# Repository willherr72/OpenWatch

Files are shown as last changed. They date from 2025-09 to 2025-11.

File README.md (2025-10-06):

# OpenWatch - Open Source Smartwatch

An open-source smartwatch project developed as a school final project. This repository contains all the necessary files for building a complete smartwatch, including mechanical designs, PCB layouts, and firmware/software code.

## 📁 Project Structure

```
OpenWatch/
├── Code/                    # All code files
│   ├── Firmware/           # Embedded firmware code
│   └── Software/           # Application software code
├── KiCad/                  # PCB design files and schematics
│   ├── Smartwatch.kicad_pcb    # Main PCB layout
│   ├── Smartwatch.kicad_sch    # Main schematic
│   ├── Smartwatch.kicad_pro    # Project file
│   ├── Usermade.pretty/        # Custom component footprints
│   └── Smartwatch-backups/     # Backup files
└── Mechanical/             # 3D models and mechanical designs
    ├── Watch Assm.SLDASM       # Main assembly
    ├── Watch Body.SLDPRT       # Watch body
    ├── Watch Top.SLDPRT        # Watch top
    └── Watch PCB.SLDPRT        # PCB mechanical model
```

## 🚀 Getting Started

### Prerequisites

- **Git** - Version control system
- **KiCad** - For PCB design and schematic editing
- **SolidWorks** (or compatible CAD software) - For mechanical design files
- **Arduino IDE** - For firmware development
- **Code editor** (VSCode, Cursor, etc.) - For software development

### Installation

1. Clone this repository to your local machine
2. Install the required software listed above
3. Open the appropriate files in their respective applications

## 📚 Git Workflow Guide

**⚠️ IMPORTANT: NEVER EDIT DIRECTLY IN MASTER BRANCH! ⚠️**

All team members MUST create a branch for their work, make changes in that branch, and then merge to main. This keeps the project organized and prevents conflicts.

This section provides the essential Git commands you'll use daily. Keep it simple and follow these steps exactly.

### First Time Setup (Do this once)

#### 1. Clone the Repository
```bash
# Clone the repository to your local machine
git clone https://github.com/willherr72/OpenWatch.git

# Navigate to the project directory
cd OpenWatch
```

#### 2. Configure Git (First time only)
```bash
# Set your name and email
git config --global user.name "Your Name"
git config --global user.email "your.email@example.com"
```

## 🚀 Daily Workflow (Follow These Steps Every Time)

### Step 1: Start Your Work Session
```bash
# 1. Get the latest changes from the team
git pull origin master

# 2. Create a new branch for your work (replace 'your-feature' with what you're working on)
git checkout -b feature/your-feature

# Example: git checkout -b feature/touch-screen
# Example: git checkout -b fix/power-bug
# Example: git checkout -b docs/update-readme
```

### Step 2: Make Your Changes
```bash
# 3. Make your changes to files (edit in your code editor)
# 4. Check what files you've changed
git status

# 5. Add your changes
git add .

# 6. Save your work with a message
git commit -m "Add your feature description here"

# 7. Push your branch to GitHub
git push origin feature/your-feature
```

## 📝 Essential Commands Cheat Sheet

| What you want to do | Command |
|---|---|
| See what files changed | `git status` |
| Add all changes | `git add .` |
| Save your work | `git commit -m "Your message"` |
| Upload to GitHub | `git push origin feature/your-branch` |
| Get team's latest work | `git pull origin master` |
| Create new branch | `git checkout -b feature/your-name` |
| Switch to master | `git checkout master` |
| See all branches | `git branch` |

## ⚠️ Important Rules

1. **ALWAYS create a branch before making changes**
2. **NEVER work directly in master branch**
3. **Use descriptive branch names** (feature/touch-screen, fix/power-bug, etc.)
4. **Write clear commit messages** (what you did, not how you did it)
5. **Pull before you push** (get latest changes first)

## 🔧 Development Guidelines

### Code Organization
- **Firmware**: Place all embedded code in `Code/Firmware/`
- **Software**: Place application code in `Code/Software/`
- **Mechanical**: Keep all CAD files in `Mechanical/`
- **PCB**: All KiCad files go in `KiCad/`

### Branch Naming Examples
- `feature/touch-screen-support`
- `fix/power-management-bug`
- `docs/update-readme`
- `feature/watch-face-display`

## 🤝 Contributing

1. Create a feature branch (`git checkout -b feature/amazing-feature`)
2. Make your changes
3. Commit your changes (`git commit -m 'Add some amazing feature'`)
4. Push to the branch (`git push origin feature/amazing-feature`)
5. Merge to master following the workflow above

## 📋 Project Status

This project is currently in active development as a school final project. The repository contains:

- ✅ Basic project structure
- ✅ KiCad PCB design files
- ✅ SolidWorks mechanical models
- 🔄 Firmware development 
- 🔄 Software development 

## 📄 License

This project is open source. Please check the LICENSE file for details.

---

**Happy Coding! 🚀**

Remember: When in doubt, `git status` is your friend!

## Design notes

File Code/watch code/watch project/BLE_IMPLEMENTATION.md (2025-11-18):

# BLE Implementation Guide for OpenWatch

## Overview

OpenWatch supports **two connection modes**: WiFi (full features) and BLE (battery saver). You can switch between them in Settings.

### Why Not Run Both Simultaneously?

While ESP32-S3 technically supports WiFi/BLE coexistence, it uses [time-division multiplexing](https://docs.espressif.com/projects/esp-idf/en/latest/esp32/api-guides/coexist.html) which can cause:
- Performance issues and packet delays
- Complex timing bugs
- Unpredictable behavior

**Solution**: Clean separation with mode toggle - just like Apple Watch and Samsung Galaxy Watch do it!

## Connection Modes

### 📡 WiFi Mode (Default) - Full Features
- ✅ Time sync via NTP servers
- ✅ Weather from NOAA API
- ✅ Full internet connectivity
- **Use when**: At home, office, or anywhere with WiFi
- **Power**: ~100-300mA during active use

### 🔵 BLE Mode - Battery Saver  
- ✅ Time sync from paired phone
- 🚧 Future: Notifications (when vibration motor added)
- 🚧 Future: Music control, find-my-phone
- **Use when**: Away from WiFi but near your phone
- **Power**: ~15-30mA during active use (10x more efficient!)
- **Note**: Weather requires WiFi - switch back to WiFi mode for weather updates

## How to Use

### On the Watch

1. Navigate to the **Settings** screen (upward swipe from watch face)
2. You'll see a **Connection** section with a toggle switch:
   - **WiFi** (left) - Default mode, connects to your WiFi network
   - **BLE** (right) - BLE mode, connects to your phone via Bluetooth
3. Toggle the switch to change modes
4. The "Mode" label will update to show the current mode

### On Your Phone

You'll need a companion app or BLE terminal to send data to the watch. Here are the BLE service UUIDs:

#### Time Sync Service (Currently Implemented)
- **Service UUID**: `12340000-1234-1234-1234-123456789abc`
- **Time Sync Characteristic**: `12340001-1234-1234-1234-123456789abc`
  - **Type**: Write
  - **Format**: 4-byte Unix timestamp (little-endian)
  - **Example**: Send `Math.floor(Date.now() / 1000)` from JavaScript

#### Future Services
- **Notification Service**: Coming when vibration motor is added
- **Music Control**: Coming in future update
- **Find My Phone**: Coming in future update

**Note**: Weather service was removed - weather requires internet, so use WiFi mode instead!

## Implementation Details

### File Structure

```
include/
  └── ble_handler.h         # BLE handler header
src/
  └── ble_handler.cpp       # BLE implementation
  └── app_manager.cpp       # Updated with BLE mode toggle
  └── main.cpp              # BLE initialization and updates
  └── wifi_handler.cpp      # Mode-aware WiFi handling
```

### Key Components

#### 1. BLE Handler (`ble_handler.cpp`)
- Manages BLE server, services, and characteristics
- Handles connection/disconnection callbacks
- Processes incoming time and weather data
- Provides mode switching functionality

#### 2. Settings Screen (`app_manager.cpp`)
- New WiFi/BLE toggle switch
- Visual mode indicator
- Event handler for mode switching

#### 3. Main Loop (`main.cpp`)
- BLE initialization
- BLE update calls
- Mode-aware time synchronization
- Mode-aware connectivity indicator

#### 4. Weather App (`app_manager.cpp`)
- Checks connection mode
- Fetches weather from WiFi API or BLE
- Displays appropriate status messages

### Mode Switching Behavior

When switching **FROM WiFi TO BLE**:
1. WiFi is disconnected and disabled
2. BLE services are started
3. Watch begins advertising as "OpenWatch"
4. WiFi icon shows BLE connection status

When switching **FROM BLE TO WiFi**:
5. BLE services are stopped and resources freed
6. WiFi reconnects automatically (handled by existing WiFi handler)
7. WiFi icon shows WiFi connection status

### Data Flow

#### Time Sync
```
Phone App → BLE Time Characteristic → ble_handler.cpp → System Time → Watch Face
```

#### Weather Data
```
Phone App → BLE Weather Characteristics → ble_handler.cpp → weather_data → Weather Screen → Watch Face
```

## No Companion App Needed!

You can sync time from your phone using existing BLE tools:

### Option 1: Use BLE Scanner Apps (Easiest)
**Android**: 
- Download "nRF Connect" from Play Store
- Connect to "OpenWatch"
- Find Time Sync characteristic (`12340001-...`)
- Write 4-byte timestamp

**iOS**:
- Download "LightBlue" from App Store  
- Connect to "OpenWatch"
- Find Time Sync characteristic
- Write timestamp as hex value

### Option 2: Web Bluetooth (Any Phone Browser)
Open this code in Chrome/Edge on your phone:

```html
<!DOCTYPE html>
<html>
<body>
<button onclick="syncTime()">Sync Time to OpenWatch</button>
<script>
let device, timeChar;

async function syncTime() {
  if (!timeChar) {
    // Connect first time
    device = await navigator.bluetooth.requestDevice({
      filters: [{ name: 'OpenWatch' }],
      optionalServices: ['12340000-1234-1234-1234-123456789abc']
    });
    const server = await device.gatt.connect();
    const service = await server.getPrimaryService('12340000-1234-1234-1234-123456789abc');
    timeChar = await service.getCharacteristic('12340001-1234-1234-1234-123456789abc');
  }
  
  // Send current time
  const timestamp = Math.floor(Date.now() / 1000);
  const buffer = new ArrayBuffer(4);
  new DataView(buffer).setUint32(0, timestamp, true);
  await timeChar.writeValue(buffer);
  alert('Time synced!');
}
</script>
</body>
</html>
```

Save this as `openwatch_sync.html` and open in your phone browser!

## Testing

### BLE Mode Testing
1. Upload firmware to watch
2. Navigate to Settings and switch to BLE mode
3. Watch should start advertising as "OpenWatch"
4. Connect from phone using BLE scanner app (e.g., nRF Connect, LightBlue)
5. Send time sync data to verify time updates
6. Send weather data to verify weather screen updates

### WiFi Mode Testing
1. Switch back to WiFi mode in Settings
2. Watch should reconnect to WiFi automatically
3. Verify time sync via NTP
4. Verify weather fetch from NOAA API

## Troubleshooting

### Watch Not Advertising
- Ensure you're in BLE mode (check Settings screen)
- Reboot the watch
- Check serial monitor for "[BLE] Services started and advertising!"

### Phone Can't Connect
- Make sure Bluetooth is enabled on phone
- Try disconnecting and reconnecting
- Check serial monitor for "[BLE] Client connected!" message

### Time Not Syncing
- Verify timestamp format (4-byte little-endian Unix time)
- Check serial monitor for "[BLE] Received time sync" message
- Try sending timestamp again (BLE sometimes drops first packet)

### Weather Not Showing
- Weather requires WiFi mode! Switch to WiFi mode in Settings
- BLE mode is for time sync and future notifications only

## Power Consumption

BLE mode is generally more power-efficient than WiFi for smartwatch applications:
- **WiFi**: ~100-300mA during active connection
- **BLE**: ~15-30mA during active connection
- **BLE Advertising**: ~10-20mA

Consider using BLE mode for better battery life when you're near your phone.

## Security Considerations

The current implementation uses **unencrypted** BLE connections. For production use, consider:
- Adding BLE pairing/bonding
- Implementing encryption for sensitive data
- Adding authentication mechanisms
- Restricting which devices can connect

## Roadmap

### Next (When Vibration Motor Added)
- [ ] Notification service - get phone notifications on watch
- [ ] Call alerts - vibrate for incoming calls
- [ ] Text message previews

### Future
- [ ] Music control - play/pause/skip from watch
- [ ] Find-my-phone - make phone ring from watch
- [ ] Battery level reporting to phone
- [ ] Secure pairing with encryption

### Won't Implement
- ~~Weather via BLE~~ - Weather needs internet, use WiFi mode
- ~~Dual WiFi+BLE~~ - Time-division multiplexing adds complexity/bugs

---

**Note**: This is a development implementation. For production use, additional security and error handling should be implemented.

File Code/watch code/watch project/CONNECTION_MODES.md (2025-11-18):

# OpenWatch Connection Modes - Quick Reference

## TL;DR
- **WiFi Mode** (default): Time + Weather ✅
- **BLE Mode** (battery saver): Time only, notifications later 🚧

## When to Use Each Mode

### Use WiFi Mode When:
- 🏠 At home or office with WiFi
- 🌤️ You want weather updates
- 🌐 You need full internet features
- 🔌 Near a charger (uses more power)

### Use BLE Mode When:
- 🚶 Away from WiFi but near your phone
- 🔋 Want to save battery (10x more efficient!)
- ⏰ Only need time sync
- 📱 Waiting for notification features (coming soon)

## How to Switch Modes

1. Swipe **UP** from watch face → Settings
2. Toggle switch: **WiFi** ← → **BLE**
3. Current mode shown below switch

## What Works in Each Mode

| Feature | WiFi Mode | BLE Mode |
|---|---|---|
| Time Sync | ✅ NTP (auto) | ✅ From phone (manual) |
| Weather | ✅ NOAA API | ❌ Need WiFi |
| Battery Life | ~8-12 hours | ~80-120 hours |
| Notifications | ❌ | 🚧 Coming soon |

## Time Sync in BLE Mode

Since you don't have WiFi in BLE mode, sync time from your phone:

### Quick Method (No App Needed!)
1. Open Chrome on your phone
2. Go to: `https://googlechromelabs.github.io/web-bluetooth/demos/`
3. Find "Generic Access" demo
4. Connect to "OpenWatch"
5. Write timestamp to characteristic `12340001-1234-1234-1234-123456789abc`

### Using BLE Scanner App
1. Download "nRF Connect" (Android) or "LightBlue" (iOS)
2. Connect to "OpenWatch"
3. Find Time Service → Time Sync characteristic
4. Write current Unix timestamp (4 bytes, little-endian)

**Tip**: Your phone likely has apps that can do this automatically!

## Technical Details

### Why Not Both at Once?
ESP32-S3 CAN run WiFi+BLE simultaneously, but it uses time-division multiplexing which causes:
- Packet delays and dropped connections
- Timing bugs and race conditions  
- Unpredictable performance

Clean separation = reliable operation! (Same approach as Apple Watch, Samsung Galaxy Watch)

### Power Consumption
- **WiFi active**: 100-300mA
- **BLE active**: 15-30mA
- **Deep sleep**: <1mA (future)

Switching to BLE mode when away from WiFi can **extend battery life by 10x**!

## Future Features (BLE Mode)

When vibration motor is added:
- 📱 Phone call alerts
- 💬 Text message notifications
- 📧 Email previews
- 🎵 Music control
- 📍 Find my phone

## Common Issues

**Q: Weather shows "Weather needs WiFi" in BLE mode**  
A: Correct! Weather requires internet. Switch to WiFi mode for weather.

**Q: Time not syncing in BLE mode**  
A: You need to manually sync from phone. See "Time Sync in BLE Mode" above.

**Q: Can I leave it in WiFi mode all the time?**  
A: Yes! WiFi is the default and works great when you have WiFi available.

**Q: Does BLE mode use my phone's data?**  
A: No! BLE is direct watch↔phone connection. No cellular data used.

## Recommendation

**Start with WiFi mode** (default) - it just works!  
Switch to **BLE mode** when you're away from WiFi to save battery.

---

*For detailed technical documentation, see `BLE_IMPLEMENTATION.md`*

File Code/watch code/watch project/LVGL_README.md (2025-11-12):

# OpenWatch - LVGL Edition

## Overview

This smartwatch firmware has been migrated to use **LVGL (Light and Versatile Graphics Library)** for a modern, beautiful UI with smooth animations and better graphics rendering.

## Features

### Current Implementation

- ✅ **Beautiful Modern Watch Face**
  - Large, clear time display (12-hour format)
  - Circular seconds indicator arc
  - Day of week and date display
  - WiFi status indicator
  - Smooth animations
  - Dark theme with cyan accents
  - Subtle glow effects

- ✅ **LVGL Integration**
  - LVGL v9.2.2
  - Optimized for 240x240 round GC9A01A display
  - Double-buffered rendering for smooth updates
  - TFT_eSPI hardware acceleration

- ✅ **Touch Input**
  - CST816S touch controller support
  - Integrated with LVGL input system

- ✅ **Power Management**
  - Button-triggered sleep mode
  - Low power light sleep
  - Wake on button press

- ✅ **Time Sync**
  - WiFi-based NTP time synchronization
  - Automatic timezone handling (CDT/CST)
  - Visual sync status indicators

## Hardware

- **MCU**: ESP32-S3 (Adafruit QT Py ESP32-S3)
- **Display**: GC9A01A 240x240 round TFT (SPI)
- **Touch**: CST816S capacitive touch controller (I2C)
- **Buttons**: 2x physical buttons

## Pin Configuration

```
Display (SPI):
- SCLK: GPIO 12
- MOSI: GPIO 11
- MISO: GPIO 13
- CS:   GPIO 10
- DC:   GPIO 39
- RST:  GPIO 40
- BL:   GPIO 7

Touch (I2C):
- SDA:  GPIO 8
- SCL:  GPIO 9
- INT:  GPIO 41
- ADDR: 0x15

Buttons:
- Primary: GPIO 18
- Menu:    GPIO 14

Power:
- Rail: GPIO 17 (set HIGH)
```

## Building

1. Open project in PlatformIO
2. Build: `pio run`
3. Upload: `pio run -t upload`
4. Monitor: `pio device monitor`

## Usage

### Buttons

- **Primary Button**
  - Long Press: Enter sleep mode

- **Menu Button**
  - Short Press: Toggle WiFi (for time sync)

### Watch Face

The watch face displays:
- Current time (12-hour format)
- Day of week (top)
- Date (bottom)
- Circular seconds indicator
- WiFi status icon (green when connected)
- Dimmed display when time not synced

## Configuration

### WiFi Credentials

Edit `include/secrets.h`:
```cpp
#define WIFI_SSID "your-ssid"
#define WIFI_PASSWORD "your-password"
```

### LVGL Settings

Configuration in `lv_conf.h`:
- Memory: 64KB heap
- Color depth: 16-bit (RGB565)
- Buffer: 40 lines (9600 pixels per buffer)
- Theme: Dark mode enabled
- Fonts: Montserrat 12-48pt

## Architecture

```
┌─────────────────────────────────────┐
│           main.cpp                  │
│  (Main loop, WiFi, time sync)       │
└─────────────────┬───────────────────┘
                  │
        ┌─────────┴─────────┐
        │                   │
┌───────▼────────┐  ┌───────▼────────┐
│  LVGL Display  │  │  LVGL Touch    │
│   (TFT_eSPI)   │  │  (CST816S)     │
└───────┬────────┘  └───────┬────────┘
        │                   │
        └─────────┬─────────┘
                  │
        ┌─────────▼─────────┐
        │   Watch Face UI   │
        │  (LVGL widgets)   │
        └───────────────────┘
```

## Future Enhancements

- Add more watch faces (analog, digital variants)
- App menu system
- Timer/stopwatch app
- Fitness tracking
- Weather display
- Notification system
- Settings menu
- Battery level indicator

## Libraries Used

- **LVGL** (v9.2.2) - Graphics library
- **TFT_eSPI** (v2.5.43) - Display driver
- **ArduinoJson** (v7.4.2) - JSON parsing
- **CST816S** (custom) - Touch driver

## Notes

- LVGL tasks run at ~30 FPS
- Watch face updates every 1 second
- WiFi disabled by default (power saving)
- Time persists via ESP32 RTC when WiFi off
- Timezone: Central Time (UTC-5)

## Troubleshooting

### Display not working
- Check SPI pin definitions in platformio.ini
- Verify TFT_BL (backlight) is HIGH
- Ensure LVGL buffer size fits in memory

### Touch not responding
- Check I2C pins and address (0x15)
- Verify pull-up resistors on I2C lines
- Check INT pin connection

### Time not syncing
- Press Menu button to enable WiFi
- Check WiFi credentials in secrets.h
- Monitor serial output for NTP status

## License

[Your License Here]

## Author

OpenWatch Project

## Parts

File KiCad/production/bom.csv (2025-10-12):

Designator | Footprint | Quantity | Value | LCSC Part #
AE1 | 1206 | 1 | Antenna_Shield
AE2 | 1206 | 1 | W3011
BT1 | PinHeader_1x02_P1.27mm_Vertical | 1 | 1S1P LiPo
C1, C6 | 0402 | 2 | 1u
C10, C2, C22, C35, C8 | 0603 | 5 | 10u
C11, C12, C13, C14, C19, C20, C21, C23, C24, C25, C26, C3, C37, C38, C4, C5, C9 | 0402 | 17 | 100n
C15, C16 | 0402 | 2 | 10p
C17, C18, C31, C32 | 0402 | 4 | 22p
C27, C28, C33, C34 | 0402 | 4 | DNP
C7 | 0402 | 1 | 10u
D1, D2, D3 | D_SOD-323 | 3 | D_Small
J1 | PinHeader_1x04_P2.54mm_Vertical | 1 | 5358
JP1 | SolderJumper-2_P1.3mm_Open_RoundedPad1.0x1.5mm | 1 | BOOT SEL
L1, L2, R24, R25, R4 | 0402 | 5 | 0
M1 | PinHeader_1x02_P1.27mm_Vertical | 1 | LCM1027B3605F
Q1 | TSOT-23 | 1 | AO3400A
R1 | 0402 | 1 | 10
R10, R14, R15, R16, R19, R2, R20, R21, R22, R23, R26, R29, R3, R6 | 0402 | 14 | 10k
R11, R7 | 0402 | 2 | 1M
R12 | 0402 | 1 | 250K
R13 | 0402 | 1 | 2K
R17, R18 | 0402 | 2 | 4.7k
R27, R28 | 0402 | 2 | 22
R5, R8, R9 | 0402 | 3 | 1k
SW1 | JXTCONN TS-1010-S26 | 1 | SW_Push
SW2 | JXTCONN TS-1010-S26 | 1 | JXTCONN TS-1010-S26
U1 | LGA-28_5.2x3.8mm_P0.5mm | 1 | BNO055
U10 | quectel lc76g | 1 | Quectel LC76G
U11 | SOT-23-5 | 1 | MIC5504-1.8YM5
U12 | QFN-56-1EP_7x7mm_P0.4mm_EP4x4mm | 1 | ESP32-S3
U13 | Bosch_LGA-8_2x2.5mm_P0.65mm_ClockwisePinNumbering | 1 | BMP280
U14 | DFN-6-1EP_3x3mm_P0.95mm_EP1.7x2.6mm | 1 | LD39100PU33R
U2 | SOT-23-5 | 1 | MIC5504-3.3YM5
U3 | Maxim_OLGA-14_3.3x5.6mm_P0.8mm | 1 | MAX30102
U4 | DFN-8-1EP_3x2mm_P0.5mm_EP1.7x1.4mm | 1 | MCP9808_DFN
U5 | SOT-583-8 | 1 | TPS2116DRL
U6 | SOT-23-6 | 1 | USBLC6-2SC6
U7 | SOT-23-5 | 1 | BRCL4054DME
U9 | JST_ZE_B13B-ZESK-D_1x13_P1.50mm_Vertical | 1 | GC9A01_IPS_Display_w/_Touch
Y1 | Crystal_SMD_2016-4Pin_2.0x1.6mm | 1 | 40MHz
Y2, Y3 | EPSON Q13FC13500004 | 2 | 32.768KHz

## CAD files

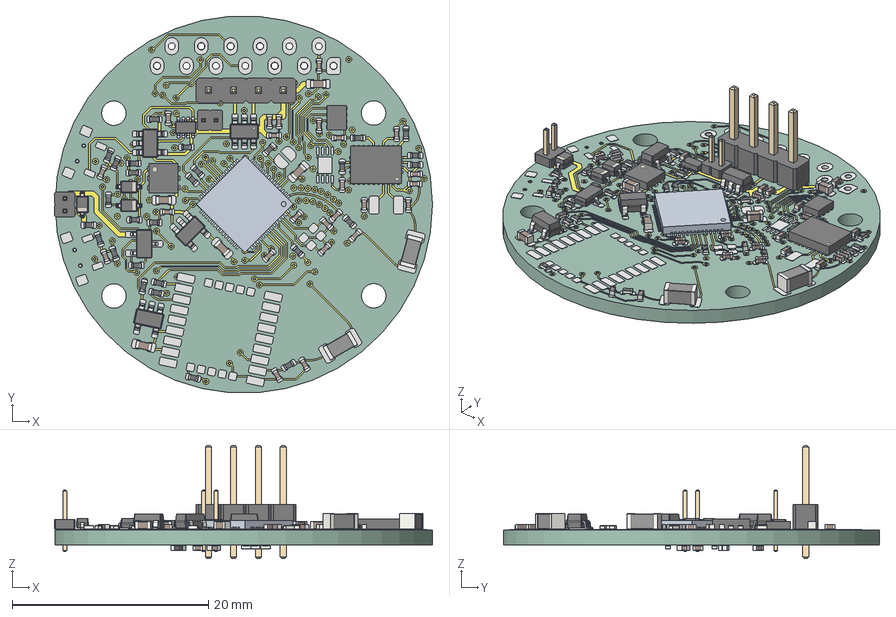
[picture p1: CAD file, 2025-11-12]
KiCad/Smartwatch.step
38.6 x 38.4 x 11.5 mm
C_0402_1005Metric x 30
R_0402_1005Metric x 31
PinHeader_1x02_P1.27mm_Vertical x 2
C_0603_1608Metric x 5
L_1206_3216Metric x 2
SOT-23-5 x 3
TSOT-23
D_SOD-323 x 3
SOT-23-6
LGA-28_5.2x3.8mm_P0.5mm
SOT-583-8
Bosch_LGA-8_2x2.5mm_P0.65mm_ClockwisePinNumbering
DFN-6-1EP_3x3mm_P0.95mm_EP1.7x2.6mm
PinHeader_1x04_P2.54mm_Vertical
Smartwatch 1.71.1
Smartwatch_copper
Smartwatch_pad
Smartwatch_via
Smartwatch_PCB

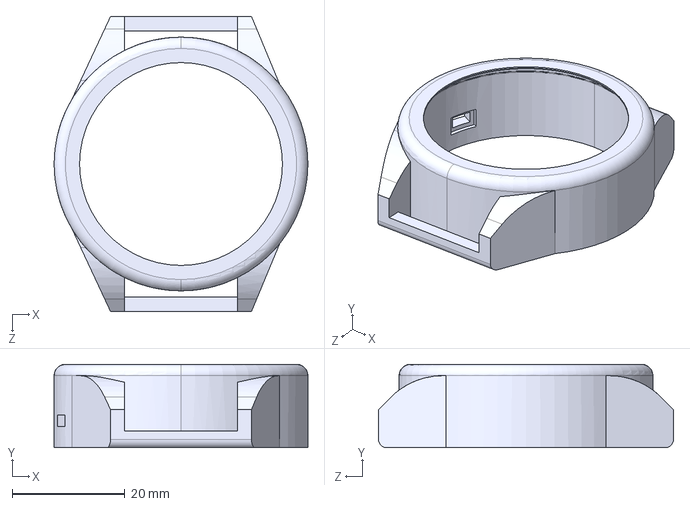
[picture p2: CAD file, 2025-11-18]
Mechanical/.step/Watch Body - Velcro.STEP
45.0 x 14.8 x 52.3 mm

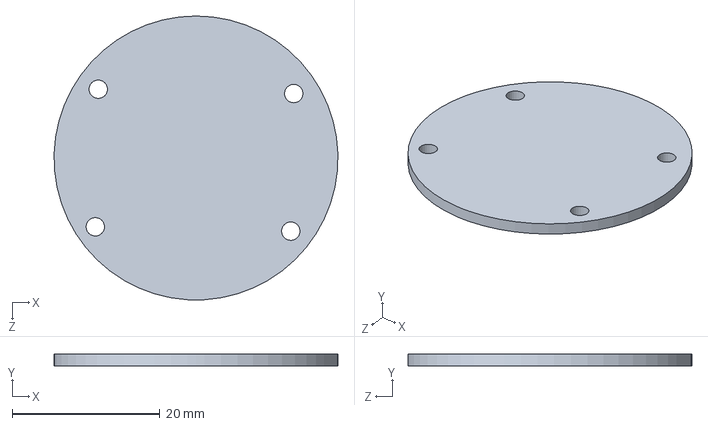
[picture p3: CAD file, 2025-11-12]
Mechanical/Watch PCB.SLDPRT
38.5 x 1.60 x 38.5 mm

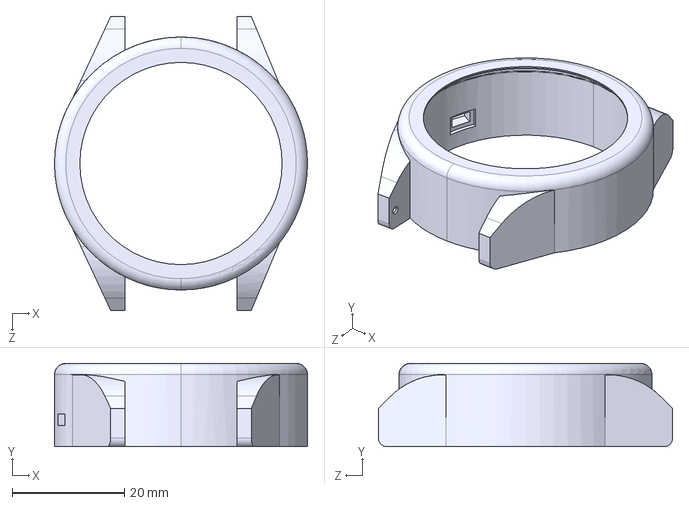
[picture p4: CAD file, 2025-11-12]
Mechanical/.step/Watch Body.STEP
45.0 x 14.8 x 52.3 mm

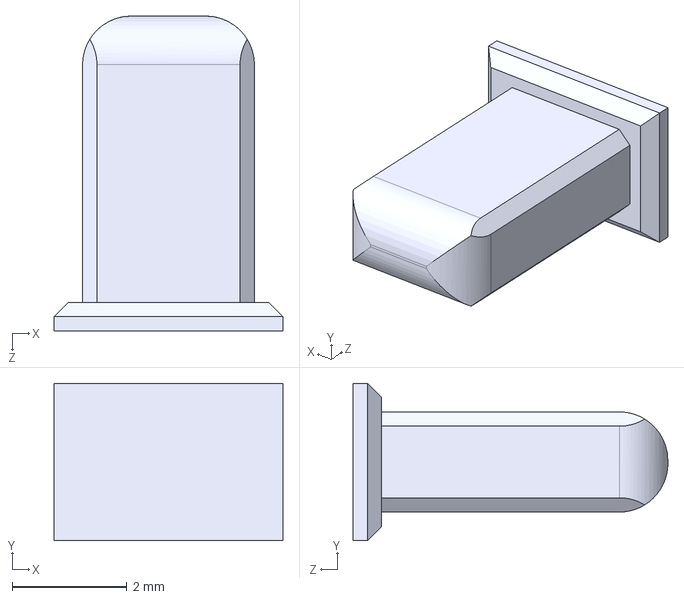
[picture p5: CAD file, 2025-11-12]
Mechanical/.step/Watch Buttons.STEP
4.00 x 2.75 x 5.50 mm

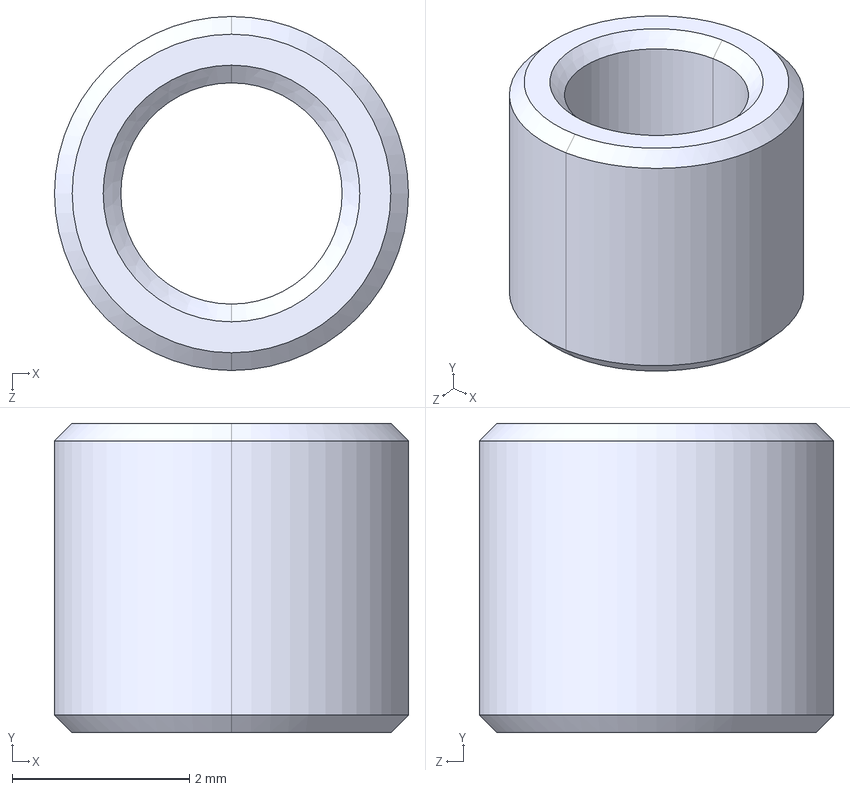
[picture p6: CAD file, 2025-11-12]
Mechanical/.step/Watch Spacer.STEP
4.00 x 3.50 x 4.00 mm

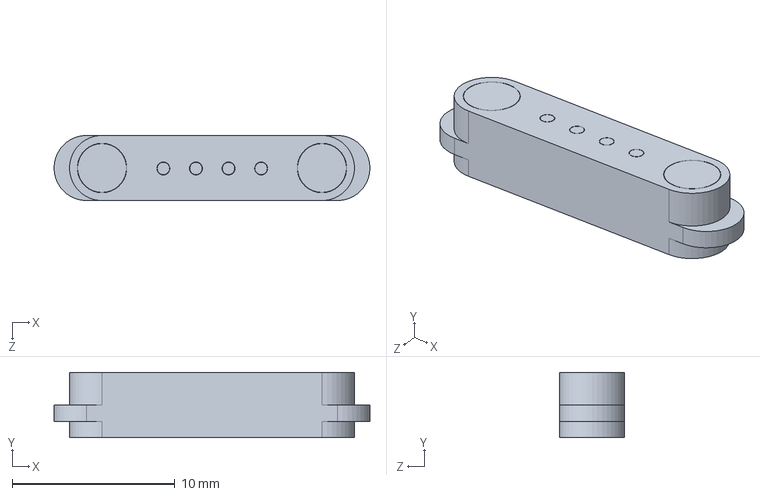
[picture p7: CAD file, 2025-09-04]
Mechanical/Magnetic Pogo Connector 4 Pin.SLDPRT
19.4 x 4.00 x 4.00 mm

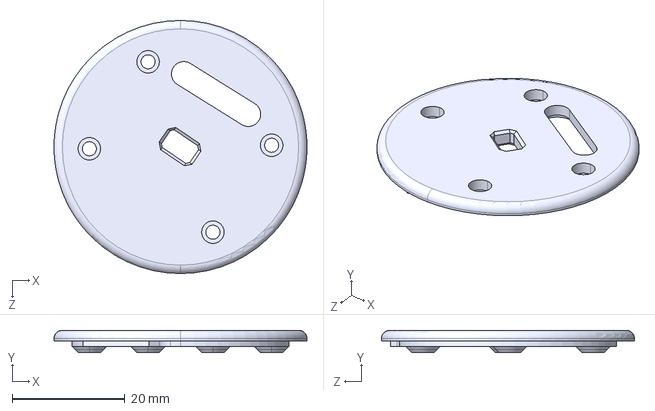
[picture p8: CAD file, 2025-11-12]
Mechanical/.step/Watch Top.STEP
45.0 x 4.00 x 45.0 mm

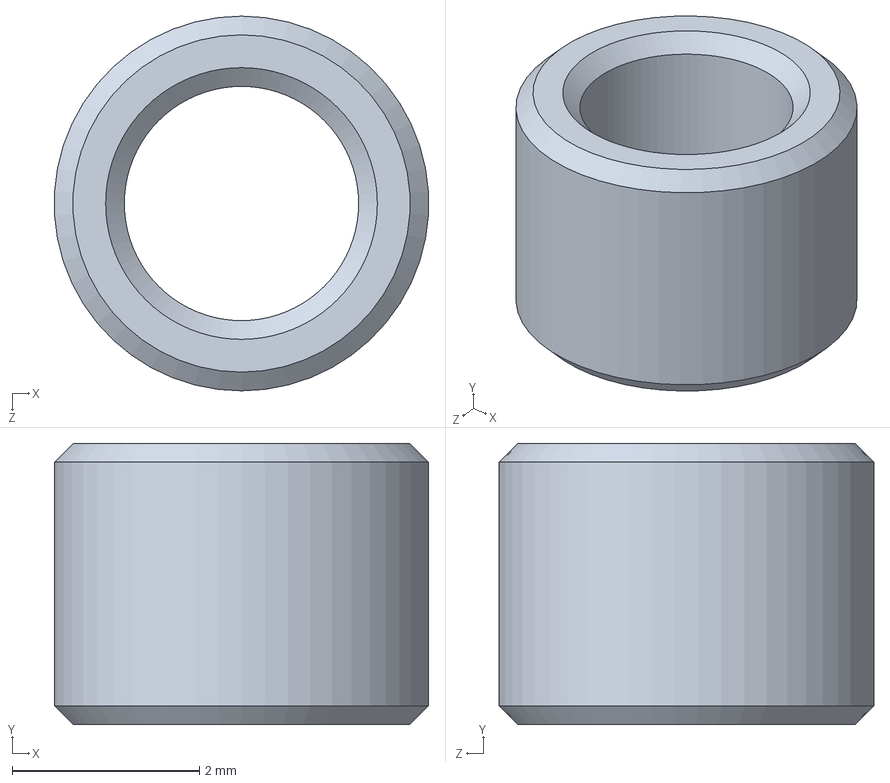
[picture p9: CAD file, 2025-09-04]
Mechanical/Watch Spacer - Long.SLDPRT
3.99 x 3.00 x 4.00 mm

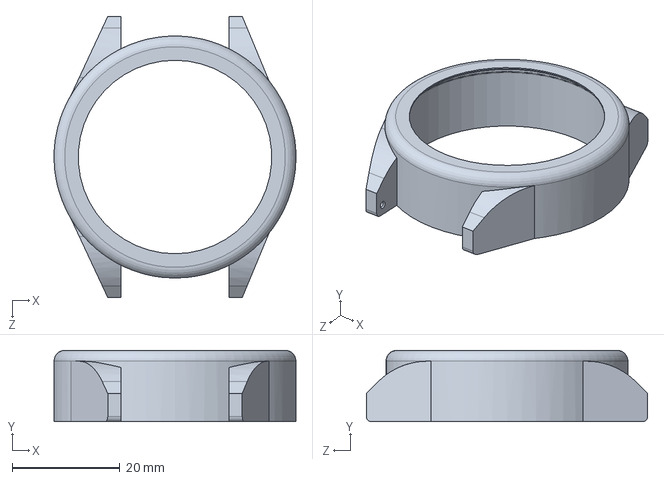
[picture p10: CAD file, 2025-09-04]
Mechanical/.step/Watch Body - First.SLDPRT
45.0 x 13.3 x 52.3 mm

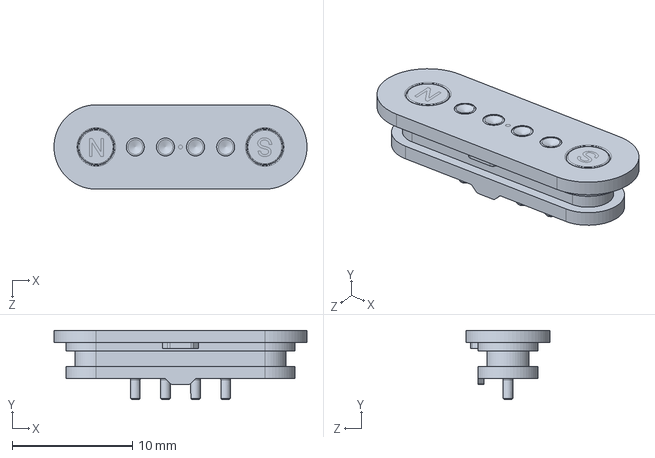
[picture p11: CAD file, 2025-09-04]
Mechanical/Magnetic Pogo Connector 4 Pin (Type 1).SLDPRT
21.0 x 5.75 x 7.00 mm

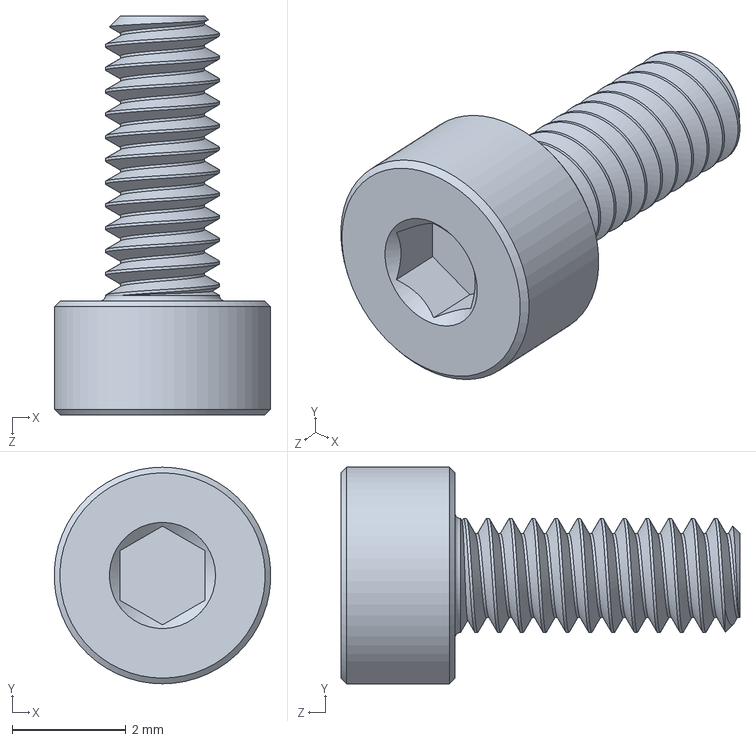
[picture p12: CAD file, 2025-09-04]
Mechanical/91290A012_Alloy Steel Socket Head Screw.SLDPRT
3.79 x 3.80 x 7.00 mm

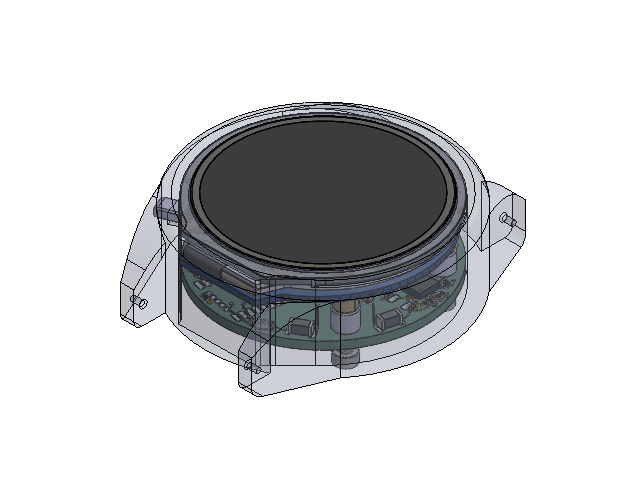
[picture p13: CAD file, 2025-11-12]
Mechanical/Watch Assm.SLDASM
Watch Body
1_28INCH-240X240-TFT_1.stp
1_28INCH-240X240-TFT-TOUCH_1.stp
1_28INCH_TOUCH_LCD-PCBA_1.stp
STUDS-M2XH2_5_1.stp x 4
Watch Spacer x 4
91290A015_Alloy Steel Socket Head Screw x 4
Magnetic Pogo Connector 4 Pin
Smartwatch 1.71.1.step
C_0402_1005Metric.step x 30
R_0402_1005Metric.step x 31
PinHeader_1x02_P1.27mm_Vertical.step x 2
C_0603_1608Metric.step x 5
L_1206_3216Metric.step x 2
SOT-23-5.step x 3
TSOT-23.step
D_SOD-323.step x 3
SOT-23-6.step
LGA-28_5.2x3.8mm_P0.5mm.step
SOT-583-8.step
Bosch_LGA-8_2x2.5mm_P0.65mm_ClockwisePinNumbering.step
DFN-6-1EP_3x3mm_P0.95mm_EP1.7x2.6mm.step
PinHeader_1x04_P2.54mm_Vertical.step
Smartwatch_copper.step
Smartwatch_pad.step
Smartwatch_via.step
Smartwatch_PCB.step
Watch Buttons x 2

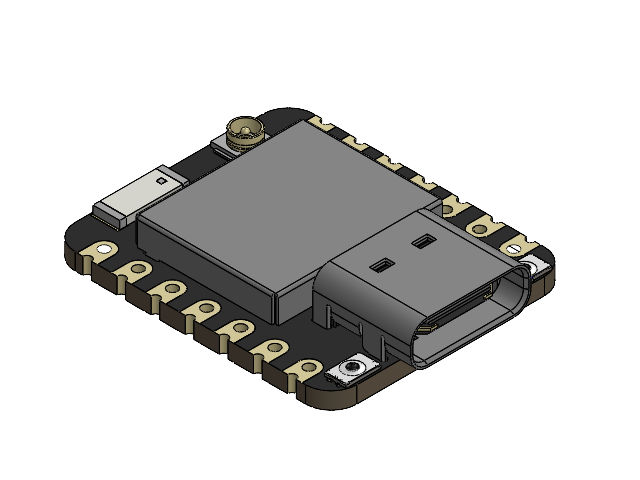
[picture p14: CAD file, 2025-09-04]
Mechanical/.step/Seeed Studio XIAO ESP32-C6.SLDASM
BOSS-EXTRUDE14_8_.step
BOSS-EXTRUDE7_4_.step
BOSS-EXTRUDE7_3_.step
BOSS-EXTRUDE14_4_.step
BOSS-EXTRUDE14_2_.step
BOSS-EXTRUDE14_11_.step
BOSS-EXTRUDE7_7_.step
BOSS-EXTRUDE14_9_.step
BOSS-EXTRUDE14_3_.step
BOSS-EXTRUDE14_7_.step
MIRROR2.step
BOSS-EXTRUDE14_5_.step
BOSS-EXTRUDE14_12_.step
BOSS-EXTRUDE7_8_.step
BOSS-EXTRUDE7_1_.step
BOSS-EXTRUDE14_10_.step
BOSS-EXTRUDE7_9_.step
BOSS-EXTRUDE14_6_.step
CHAMFER9.step
BOSS-EXTRUDE14_1_.step
BOSS-EXTRUDE7_6_.step
BOSS-EXTRUDE7_2_.step
CUT-EXTRUDE5.step
BOSS-EXTRUDE7_5_.step
U.FL Connector v1.step
Shield.step
Seeed Studio XIAO-ESP32-C6-0.step
Seeed Studio XIAO-ESP32-C6-1.step
Seeed Studio XIAO-ESP32-C6-2.step
SKTAAAE010.step x 2
KH5220-A36 (Ceramic Antenna) v2.step

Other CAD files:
Mechanical/1_28inch-touch-lcd-sku24155.SLDASM
Mechanical/Watch Body - Velcro.SLDPRT
Mechanical/Watch Body.SLDPRT
Mechanical/Watch Buttons.SLDPRT
Mechanical/Watch PCB.DXF
Mechanical/Watch Spacer.SLDPRT
Mechanical/Watch Top.SLDPRT

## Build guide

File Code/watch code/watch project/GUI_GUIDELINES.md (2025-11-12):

# OpenWatch GUI Navigation Guidelines

## Overview
This document outlines the navigation structure and user interface guidelines for the OpenWatch smartwatch application.

## Main Navigation Structure

### Primary Navigation (Vertical Swipes from Watch Face)

The watch face is the central hub. Vertical swipes navigate through main app screens in a linear sequence:

```

┌─────────────────────────────────────┐
│            Settings                 │
│        (Current: Active)            │
│    ↑ Swipe UP: Back to Watch Face   │
│    ↓ Swipe DOWN: NA                 │
└─────────────────────────────────────┘
                 ↓
┌─────────────────────────────────────┐
│         Watch Face (Home)           │
│                                     │
│    ↑ Swipe DOWN: Enter settings     │
│    ↓ Swipe UP: Return from below    │
└─────────────────────────────────────┘
                 ↑
┌─────────────────────────────────────┐
│            Weather                  │
│           (Future Dev)              │
│    ↑ Swipe UP: Fitness              │
│    ↓ Swipe DOWN: Watch Face         │
└─────────────────────────────────────┘
                 ↑
┌─────────────────────────────────────┐
│            Fitness                  │
│           (Future Dev)              │
│    ↑ Swipe UP: Music                │
│    ↓ Swipe DOWN: Weather            │
└─────────────────────────────────────┘
                 ↑
┌─────────────────────────────────────┐
│             Music                   │
│           (Future Dev)              │
│    ↑ Swipe UP: Navigation           │
│    ↓ Swipe DOWN: Fitness            │
└─────────────────────────────────────┘
                 ↑
┌─────────────────────────────────────┐
│          Navigation                 │
│           (Future Dev)              │
│    ↑ Swipe UP: Back to Watch Face   │
│    ↓ Swipe DOWN: Music              │
└─────────────────────────────────────┘
```

### Desired Swipe Flow Sequence:
1. **Watch Face** (starting point)
2. Swipe DOWN → **Settings**
3. Swipe UP → **Weather**
4. Swipe UP → **Fitness**
5. Swipe UP → **Music**
6. Swipe UP → **Navigation**
7. Swipe UP → **Back to Watch Face** (loops back to start)

**Note:** Swiping DOWN at any point goes back to the previous screen in the sequence.

## Secondary Navigation (Horizontal Swipes - Future Development)

### Within Each App Screen
Once inside any main app (Settings, Weather, Fitness, Music, Navigation), horizontal swipes navigate sub-menus:

- **Swipe LEFT/RIGHT**: Navigate between sub-screens within that app
- Example for Settings:
  ```
  Settings Main → LEFT/RIGHT → WiFi Settings
                → LEFT/RIGHT → Bluetooth Settings
                → LEFT/RIGHT → Display Settings
                → etc.
  ```

### Current Implementation (Temporary - Will be replaced)
**Legacy horizontal navigation from watch face:**
- Swipe LEFT from Watch Face → Music (direct access)
- Swipe RIGHT from Watch Face → Heart Rate (direct access)

**This will be deprecated** once the new vertical menu structure is fully implemented.

## Design Principles

### 1. **Vertical Navigation = Main Menu Hierarchy**
   - Swipe down to go deeper into menus
   - Swipe down to go back/up in hierarchy
   - Linear, predictable flow

### 2. **Horizontal Navigation = Sub-Menu Browsing**
   - Used only within a specific app/screen
   - Browse related settings or options
   - Swipe left/right to cycle through options

### 3. **Home is Always Accessible**
   - Watch face is the main "home" screen
   - Can return to home from any screen with repeated swipes UP
   - Long press button can also return to home (alternative)

### 4. **Circular Flow**
   - The menu "wraps around" - swiping down from Navigation returns to Watch Face
   - This creates an infinite loop for easy navigation

## Screen Layouts

### Watch Face Requirements
- Display time (analog + digital)
- Show key status indicators:
  - Battery level (top)
  - Steps counter (lower left)
  - Heart rate (bottom center)
  - Weather temp (lower right)
  - WiFi/BT/Notifications (center below hands)
- Date display (left side)
- All elements must fit within circular 240x240 display

### Settings Screen Requirements
- Circular menu layout (like LVGL demo reference)
- Main options arranged in a circle:
  - WiFi (top)
  - Bluetooth (right)
  - Find Phone (bottom right)
  - More Settings (left)
- No "SELECT" or "HOME" text labels (cleaner design)
- Swipe hint at bottom

### Other App Screens
- Each screen should have:
  - Clear title/header
  - Main content area
  - Swipe hints when appropriate
  - Consistent dark theme (#000000 background)
  - Color-coded visual elements

## Color Scheme

### Primary Colors
- **Background**: `#000000` (black) to `#0a0a0a` (near black)
- **Text Primary**: `#FFFFFF` (white)
- **Text Secondary**: `#888888` (gray)
- **Text Dim**: `#666666`, `#444444` (darker grays)

### Accent Colors by Function
- **Battery/Cyan**: `#00d9ff` (cyan/blue)
- **Warning/Orange**: `#FFB74D` (gold/orange)
- **Steps**: `#FF6B35` (orange)
- **Heart Rate**: `#FF4444` (red)
- **Weather**: `#88CCFF` (light blue)
- **Music**: `#BB86FC` (purple)

## Touch Gesture Specifications

### Swipe Detection Parameters
- **Minimum swipe distance**: 60 pixels
- **Maximum swipe time**: 500ms
- **Gesture priority**: Favor direction with larger delta

### Gesture Types
1. **Swipe Up**: Vertical delta < -60px
2. **Swipe Down**: Vertical delta > 60px
3. **Swipe Left**: Horizontal delta < -60px
4. **Swipe Right**: Horizontal delta > 60px
5. **Tap**: Touch and release in < 500ms with < 10px movement (future)
6. **Long Press**: Hold for > 1000ms (current button behavior)

## Animation Guidelines

### Screen Transitions
- **Duration**: 300ms (smooth but responsive)
- **Direction matches swipe**:
  - Swipe down → slide from bottom
  - Swipe up → slide from top
  - Swipe left → slide from left
  - Swipe right → slide from right

### Element Animations
- **Clock hands**: Update smoothly every second/minute
- **Arcs/Progress**: Smooth value transitions
- **Fade in/out**: Use for overlays and non-directional transitions

## Future Development Roadmap

### Phase 1: Core Navigation (Current)
- [x] Watch face with status indicators
- [x] Settings menu with circular layout
- [x] Basic swipe detection
- [ ] Complete vertical menu structure

### Phase 2: Main Apps
- [ ] Weather app with forecast
- [ ] Fitness app with activity tracking
- [ ] Music player with Bluetooth control
- [ ] Navigation app with GPS

### Phase 3: Sub-Menus
- [ ] Settings sub-menus (WiFi config, BT pairing, etc.)
- [ ] Weather details (hourly, daily, radar)
- [ ] Fitness details (goals, history, workouts)
- [ ] Music playlists and controls

### Phase 4: Advanced Features
- [ ] Notifications system
- [ ] Heart rate monitoring integration
- [ ] Real-time sensor data
- [ ] Voice control
- [ ] App store/watchfaces

## Technical Notes

### Display Specifications
- **Resolution**: 240x240 pixels
- **Shape**: Circular
- **Driver**: GC9A01A
- **Touch**: CST816S capacitive touch controller

### Software Stack
- **Graphics**: LVGL v8.3.11
- **MCU**: ESP32-S3 @ 240MHz
- **Framework**: Arduino/PlatformIO
- **Language**: C++

### Performance Targets
- **Screen refresh**: 60 FPS minimum
- **Touch latency**: < 50ms
- **Animation smoothness**: 60 FPS during transitions
- **Battery life**: TBD (power optimization ongoing)

## Notes
- NFC functionality is not included (hardware not available)
- Current implementation has temporary horizontal navigation that will be replaced
- All future apps should follow the vertical menu structure
- Maintain consistent visual language across all screens
- Prioritize usability in circular display format

---

**Document Version**: 1.0  
**Last Updated**: 2025-01-12  
**Status**: Living Document - Update as features are implemented

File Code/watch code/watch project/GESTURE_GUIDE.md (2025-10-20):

# OpenWatch Touch Gesture Guide

## Implemented Gestures

All gestures are defined in `include/touch_input.h` as part of the `TouchGesture` enum.

### Gesture Types and Codes

| Gesture | Code | Hex | Description | Status |
|---|---|-----|---|---|
| NONE | 0x00 | 0x00 | No gesture detected | ✓ |
| SWIPE_UP | 0x01 | 0x01 | Upward swipe motion | ✓ Implementation Ready |
| SWIPE_DOWN | 0x02 | 0x02 | Downward swipe motion | ✓ Implementation Ready |
| SWIPE_LEFT | 0x03 | 0x03 | Leftward swipe motion | ✓ Implementation Ready |
| SWIPE_RIGHT | 0x04 | 0x04 | Rightward swipe motion | ✓ Used (Open Menu) |
| SINGLE_CLICK | 0x05 | 0x05 | Single tap on screen | ✓ Implementation Ready |
| DOUBLE_CLICK | 0x0B | 0x0B | Double tap on screen | ✓ Used (Tap & Hold) |
| LONG_PRESS | 0x0C | 0x0C | Long press hold | ✓ Implementation Ready |

## Currently Used Gestures

### Menu
- **SWIPE_UP** → Previous app
- **SWIPE_DOWN** → Next app
- **SWIPE_LEFT** → Enter selected app
- **SWIPE_RIGHT** → Enter selected app

### Timer App
- **SWIPE_UP** → Previous preset (1m → 5m → 10m)
- **SWIPE_DOWN** → Next preset
- **Tap & Hold (500ms)** → Start timer (in SELECTING state)
- **SWIPE_DOWN** → Cancel timer (in RUNNING state)
- **Tap & Hold (500ms)** → Reset timer (in DONE state)

### Clock App
- Available for custom implementation

## Available for Implementation

The following gestures are detected and logged but not yet assigned to functions:

- **SINGLE_CLICK** (0x05)
- **LONG_PRESS** (0x0C)
- **SWIPE_LEFT** (in most contexts, currently available only in menu for app entry)

## Gesture Detection Pipeline

1. **Hardware Detection** (CST816T in MIXED mode)
   - Detects swipes, clicks, and long-press
   - Returns gesture code and touch coordinates

2. **Software Enhancement**
   - Double-tap detection with 350ms window
   - Tap-and-hold tracking (500ms for timer)
   - Touch coordinate smoothing (4-sample average)

3. **Gesture Deduplication**
   - Prevents repeated processing of same gesture
   - Clears gesture state after 50ms of no input

4. **Logging**
   - All gestures logged to serial with readable names
   - Format: `[GESTURE] GESTURE_NAME at (x, y)`
   - Hardware gestures also logged with codes

## Adding New Gesture Handlers

### In Menu (app_manager.cpp)
```cpp
case GESTURE_SINGLE_CLICK:
  // Handle single click in menu
  Serial.println("Menu: Single click");
  break;
```

### In Timer App (timer_app.cpp)
```cpp
if (touchPoint.gesture == TouchGesture::LONG_PRESS) {
  // Handle long press in timer
  Serial.println("Timer: Long press detected");
}
```

### In Clock App (clock_display.cpp)
```cpp
if (touchPoint.gesture == TouchGesture::SINGLE_CLICK) {
  // Handle single click on clock
  Serial.println("Clock: Single click detected");
}
```

## Gesture Configuration

The CST816T can be configured in three modes:

- **Mode 0**: Gesture only (no coordinates)
- **Mode 1**: Point mode (coordinates only)
- **Mode 2**: Mixed mode (both - currently used) ✓

Current configuration in `touch_input.cpp`:
```cpp
CST816_MODE_MIXED  // Enables both gestures and touch coordinates
```

## Debugging

Enable serial monitor to see all detected gestures:

1. Build and upload
2. Open Serial Monitor at 115200 baud
3. Observe gesture detection in real-time:
   ```
   GESTURE DETECTED: gesture=0x01 (SWIPE_UP), raw(120,100) smooth(119,101) mapped(120,100) touching=0
   [GESTURE] SWIPE_UP at (120, 100)
   ```

## Performance Notes

- Touch input polled every loop iteration for accurate double-tap detection
- Display updated at 500ms interval (separate from touch processing)
- Gesture deduplication prevents redundant processing
- Serial logging can be disabled for production to save CPU cycles

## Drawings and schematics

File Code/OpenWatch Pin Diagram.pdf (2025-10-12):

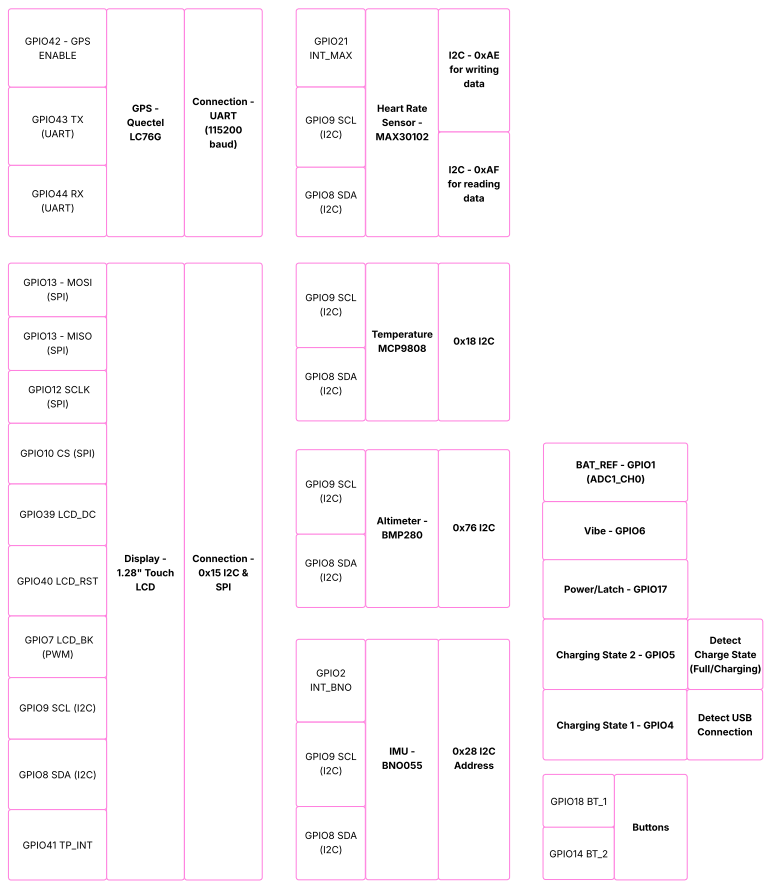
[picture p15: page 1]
GPIO43 TX (UART); GPIO44 RX (UART); Display - 1.28" Touch LCD; GPIO13 - MOSI (SPI); GPIO13 - MISO (SPI); GPIO12 SCLK (SPI); GPIO10 CS (SPI); GPIO39 LCD_DC; GPIO40 LCD_RST; GPIO7 LCD_BK (PWM); GPIO9 SCL (I2C); GPIO8 SDA (I2C); GPIO41TP_INT; Connection - 0x15 I2C & SPI; Heart Rate Sensor - MAX30102; I2C - 0xAE for writing data; I2C - 0xAF for reading data; GPIO21 INT_MAX; Temperature MCP9808; Altimeter - BMP280; IMU - BNO055; 0x28 I2C Address; Vibe - GPIO6; Power/Latch - GPIO17; GPIO14 BT_2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

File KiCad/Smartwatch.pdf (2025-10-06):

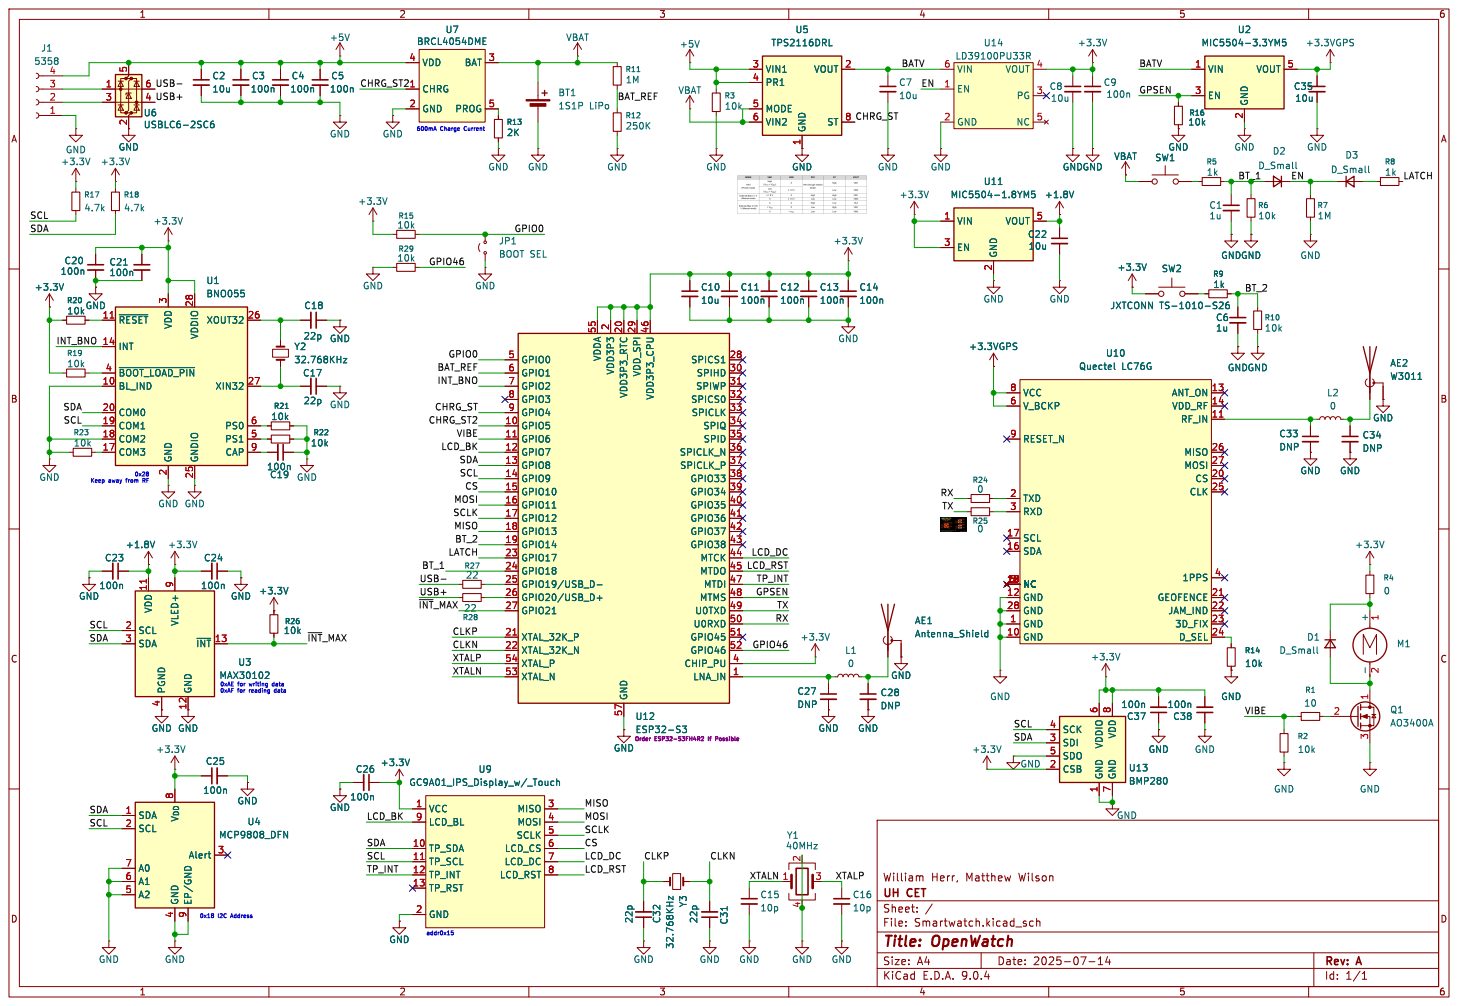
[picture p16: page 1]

2 VDDIO 28 GNDIO 25 XOUT32 26 XIN32 27 PS0 6 PS1 5 CAP 9 U1BNO055 R19 10k GND

2 VDDIO 28 GNDIO 25 XOUT32 26 XIN32 27 PS0 6 PS1 5 CAP 9 R20 10k GND

2 VDD3P3_RTC 20 GND 57 VDD_SPI 29 VDD3P3_CPU 46 SPICS1 28 SPIHD 30 SPIWP 31 SPICS0 32 SPICLK 33 SPIQ 34 SPID 35 SPICLK_P 37 GPIO33 38 GPIO34 39 GPIO35 40 GPIO36 41 GPIO37 42 GPIO38 43 MTCK 44 MTDI 47 MTMS 48 U0TXD 49 U0RXD 50 GPIO46 52 CHIP_PU 4

0x28 Keep away from RF

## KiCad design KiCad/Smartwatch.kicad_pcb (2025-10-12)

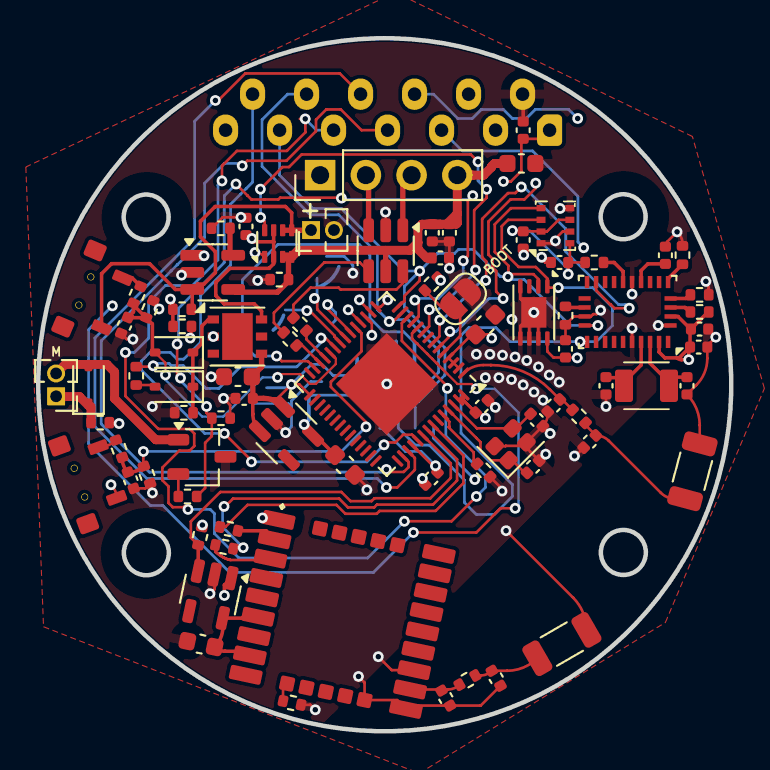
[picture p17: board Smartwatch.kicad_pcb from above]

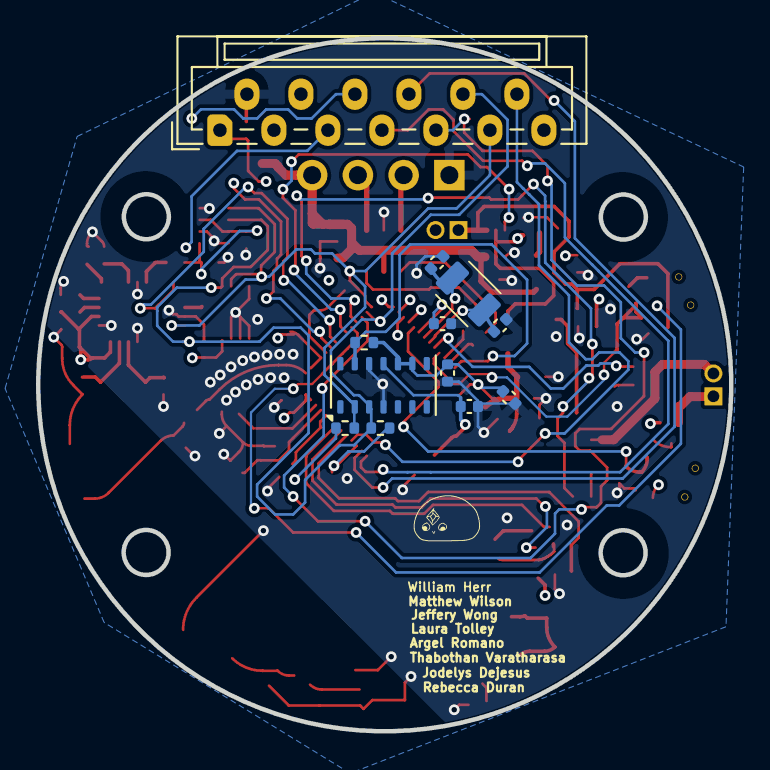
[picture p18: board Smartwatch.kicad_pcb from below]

Board: 4 copper layers, 38.5 x 38.5 mm, 94 parts (12 on the bottom side), 64 nets.

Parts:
AE1: Antenna_Shield; L_1206_3216Metric
AE2: W3011; L_1206_3216Metric
BT1: 1S1P LiPo; PinHeader_1x02_P1.27mm_Vertical
C1, C6: 1u; C_0402_1005Metric
C2, C8, C10, C22, C35: 10u; C_0603_1608Metric
C3, C4, C5, C9, C11, C12, C13, C14, C19, C20, C21, C23, C24, C25, C26, C37, C38: 100n; C_0402_1005Metric
C7: 10u; C_0402_1005Metric
C15, C16: 10p; C_0402_1005Metric
C17, C18, C31, C32: 22p; C_0402_1005Metric
C27, C28, C33, C34: DNP; C_0402_1005Metric
D1, D2, D3: D_Small; D_SOD-323
J1: 5358; PinHeader_1x04_P2.54mm_Vertical
JP1: BOOT SEL; SolderJumper-2_P1.3mm_Open_RoundedPad1.0x1.5mm
L1, L2: 0; R_0402_1005Metric
M1: LCM1027B3605F; PinHeader_1x02_P1.27mm_Vertical
Q1: AO3400A; TSOT-23
R1: 10; R_0402_1005Metric
R2, R3, R6, R10, R14, R15, R16, R19, R20, R21, R22, R23, R26, R29: 10k; R_0402_1005Metric
R4, R24, R25: 0; R_0402_1005Metric
R5, R8, R9: 1k; R_0402_1005Metric
R7, R11: 1M; R_0402_1005Metric
R12: 250K; R_0402_1005Metric
R13: 2K; R_0402_1005Metric
R17, R18: 4.7k; R_0402_1005Metric
R27, R28: 22; R_0402_1005Metric
SW1: SW_Push; JXTCONN TS-1010-S26
SW2: JXTCONN TS-1010-S26
U1: BNO055; LGA-28_5.2x3.8mm_P0.5mm
U2: MIC5504-3.3YM5; SOT-23-5
U3: MAX30102; Maxim_OLGA-14_3.3x5.6mm_P0.8mm
U4: MCP9808_DFN; DFN-8-1EP_3x2mm_P0.5mm_EP1.7x1.4mm
U5: TPS2116DRL; SOT-583-8
U6: USBLC6-2SC6; SOT-23-6
U7: BRCL4054DME; SOT-23-5
U9: GC9A01_IPS_Display_w/_Touch; JST_ZE_B13B-ZESK-D_1x13_P1.50mm_Vertical
U10: Quectel LC76G; quectel lc76g
U11: MIC5504-1.8YM5; SOT-23-5
U12: ESP32-S3; QFN-56-1EP_7x7mm_P0.4mm_EP4x4mm
U13: BMP280; Bosch_LGA-8_2x2.5mm_P0.65mm_ClockwisePinNumbering
U14: LD39100PU33R; DFN-6-1EP_3x3mm_P0.95mm_EP1.7x2.6mm
Y1: 40MHz; Crystal_SMD_2016-4Pin_2.0x1.6mm
Y2, Y3: 32.768KHz; EPSON Q13FC13500004

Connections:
+1.8V: C22.1, C23.1, U3.11 (VDD), U11.5 (VOUT)
+3.3V: C8.1, C9.1, C10.1, C11.1, C12.1, C13.1, C14.1, C20.1, C21.1, C24.2, C25.1, C26.1, C37.2, C38.2, R4.2, R15.2, R17.1, R18.1, R19.2, R20.2, R26.1, SW2.1, U1.3 (VDD), U1.28 (VDDIO), U3.9 (VLED+), U3.10 (VLED+), U4.8 (V_{DD}), U9.1 (VCC), U11.1 (VIN), U11.3 (EN), U12.2 (VDD3P3), U12.3 (VDD3P3), U12.4 (CHIP_PU), U12.20 (VDD3P3_RTC), U12.29 (VDD_SPI), U12.46 (VDD3P3_CPU), U12.55 (VDDA), U12.56 (VDDA), U13.2 (CSB), U13.6 (VDDIO), U13.8 (VDD), U14.4 (VOUT)
+3.3VGPS: C35.1, U2.5 (VOUT), U10.6 (V_BCKP), U10.8 (VCC)
+5V: C2.1, C3.1, C4.1, C5.1, J1.4, R3.2, U5.3 (VIN1), U5.4 (PR1), U6.5 (VBUS), U7.4 (VDD)
/BATV: C7.1, U2.1 (VIN), U5.2 (VOUT), U5.7 (VOUT), U14.6 (VIN)
/BAT_REF: R11.1, R12.2, U12.6 (GPIO1)
/BT_1: C1.1, D2.2 (A), R5.1, R6.2, U12.24 (GPIO18)
/BT_2: C6.1, R9.1, R10.2, U12.19 (GPIO14)
/CHRG_ST: U5.8 (ST), U12.9 (GPIO4)
/CHRG_ST2: U7.1 (CHRG), U12.10 (GPIO5)
/CLKN: C31.2, U12.22 (XTAL_32K_N), Y3.2
/CLKP: C32.2, U12.21 (XTAL_32K_P), Y3.1
/CS: U9.6 (LCD_CS), U12.15 (GPIO10)
/EN: D2.1 (K), D3.1 (K), R7.2, U14.1 (EN)
/GPIO0: JP1.2 (B), R15.1, U12.5 (GPIO0)
/GPIO46: R29.1, U12.52 (GPIO46)
/GPSEN: R16.1, U2.3 (EN), U12.48 (MTMS)
/INT_BNO: U1.14 (INT), U12.7 (GPIO2)
/LATCH: R8.1, U12.23 (GPIO17)
/LCD_BK: U9.9 (LCD_BL), U12.12 (GPIO7)
/LCD_DC: U9.7 (LCD_DC), U12.44 (MTCK)
/LCD_RST: U9.8 (LCD_RST), U12.45 (MTDO)
/MISO: U9.3 (MISO), U12.18 (GPIO13)
/MOSI: U9.4 (MOSI), U12.16 (GPIO11)
/RX: R24.1, U12.50 (U0RXD)
/SCL: R17.2, U1.19 (COM1), U3.2 (SCL), U4.2 (SCL), U9.11 (TP_SCL), U12.14 (GPIO9), U13.4 (SCK)
/SCLK: U9.5 (SCLK), U12.17 (GPIO12)
/SDA: R18.2, U1.20 (COM0), U3.3 (SDA), U4.1 (SDA), U9.10 (TP_SDA), U12.13 (GPIO8), U13.3 (SDI)
/TP_INT: U9.12 (TP_INT), U12.47 (MTDI)
/TX: R25.1, U12.49 (U0TXD)
/USB+: R28.2, U6.4 (I/O2)
/USB-: R27.2, U6.6 (I/O1)
/VIBE: R1.1, R2.2, U12.11 (GPIO6)
/XTALN: C15.1, U12.53 (XTAL_N), Y1.1
/XTALP: C16.1, U12.54 (XTAL_P), Y1.3
/~INT_MAX: R26.2, U3.13 (~INT), U12.27 (GPIO21)
GND: AE1.2 (Shield), AE2.2 (Shield), BT1.2 (-), C1.2, C2.2, C3.2, C4.2, C5.2, C6.2, C7.2, C8.2, C9.2, C10.2, C11.2, C12.2, C13.2, C14.2, C15.2, C16.2, C17.1, C18.1, C19.1, C20.2, C21.2, C22.2, C23.2, C24.1, C25.2, C26.2, C27.2, C28.2, C31.1, C32.1, C33.2, C34.2, C35.2, C37.1, C38.1, J1.1, JP1.1 (A), Q1.3 (S), R2.1, R3.1, R6.1, R7.1, R10.1, R12.1, R13.1, R14.1, R16.2, R21.2, R22.2, R23.2, R29.2, U1.2 (GND), U1.10 (BL_IND), U1.18 (COM2), U1.25 (GNDIO), U2.2 (GND), U3.4 (PGND), U3.12 (GND), U4.4 (GND), U4.5 (A2), U4.6 (A1), U4.7 (A0), U4.9 (EP/GND), U5.1 (GND), U6.2 (GND), U7.2 (GND), U9.2 (GND), U10.1 (GND), U10.10 (GND), U10.12 (GND), U10.28 (GND), U11.2 (GND), U12.57 (GND), U13.1 (GND), U13.5 (SDO), U13.7 (GND), U14.2 (GND), Y1.2, Y1.4
unnamed: AE1.1 (A), C28.1, L1.2
unnamed: AE2.1 (A), C34.1, L2.2
unnamed: D1.2 (A), M1.2 (-), Q1.1 (D)
unnamed: D1.1 (K), M1.1 (+), R4.1
unnamed: D3.2 (A), R8.2
unnamed: J1.2, U6.3 (I/O2)
unnamed: J1.3, U6.1 (I/O1)
unnamed: Q1.2 (G), R1.2
unnamed: R5.2, SW1.2
unnamed: R9.2, SW2.2
unnamed: C19.2, U1.9 (CAP)
unnamed: R23.1, U1.17 (COM3)
unnamed: R21.1, U1.6 (PS0)
unnamed: R22.1, U1.5 (PS1)
unnamed: C17.2, U1.27 (XIN32), Y2.1
unnamed: C18.2, U1.26 (XOUT32), Y2.2
unnamed: R19.1, U1.4 (~BOOT_LOAD_PIN)
unnamed: R20.1, U1.11 (~RESET)
unnamed: R13.2, U7.5 (PROG)
unnamed: R14.2, U10.24 (D_SEL)
unnamed: C33.1, L2.1, U10.11 (RF_IN)
unnamed: R25.2, U10.3 (RXD)
unnamed: R24.2, U10.2 (TXD)
unnamed: R27.1, U12.25 (GPIO19/USB_D-)
unnamed: R28.1, U12.26 (GPIO20/USB_D+)
unnamed: C27.1, L1.1, U12.1 (LNA_IN)
VBAT: BT1.1 (+), R11.2, SW1.1, U5.5 (MODE), U5.6 (VIN2), U7.3 (BAT)

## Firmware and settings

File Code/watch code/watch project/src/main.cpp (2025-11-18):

#include <Arduino.h>
#include <Wire.h>
#include <WiFi.h>
#include <SPI.h>
#include <Adafruit_GC9A01A.h>
#include <lvgl.h>
#include "secrets.h"
#include "lvgl_display.h"
#include "lvgl_touch.h"
#include "watch_face.h"
#include "app_manager.h"
#include "button_handler.h"
#include "wifi_handler.h"
#include "sensor_handler.h"
#include "ble_handler.h"
#include "vibration.h"

/* SPI and TFT Display */
SPIClass displaySPI(FSPI);
Adafruit_GC9A01A tft = Adafruit_GC9A01A(&displaySPI, TFT_DC_PIN, TFT_CS_PIN, TFT_RST_PIN);

/* Button handlers */
ButtonHandler button(BUTTON_PRIMARY_PIN);        // GPIO18 - Power menu button (3-second hold)
ButtonHandler menuButton(MENU_BUTTON_PIN);      // GPIO14 - Home button (return to watch face)

/* GPIO18 power menu state tracking */
unsigned long gpio18_press_start = 0;
bool gpio18_pressed = false;
bool power_menu_shown = false;

/* Time synchronization */
bool timeSynced = false;
unsigned long lastWiFiAttempt = 0;
unsigned long lastNtpAttempt = 0;
unsigned long lastWiFiCheckTime = 0;  // For throttling WiFi operations

/* Touch retry */
bool touchInitialized = false;
unsigned long lastTouchRetry = 0;
const unsigned long TOUCH_RETRY_INTERVAL = 200;  // Retry every 200ms for quick response

// ═══════════════════════════════════════════════════════════════════════
// TIMEZONE CONFIGURATION - Change timezone here
// ═══════════════════════════════════════════════════════════════════════
// Central Standard Time (CST) = UTC-6 (DST ended Nov 2, 2025)
const long TIMEZONE_OFFSET_SEC = -21600;  // -6 hours * 3600 = -21600 seconds
// 
// Other common US timezones:
// CDT (Central Daylight Time) = -18000  (UTC-5)
// EST (Eastern Standard Time) = -18000  (UTC-5)  
// EDT (Eastern Daylight Time) = -14400  (UTC-4)
// PST (Pacific Standard Time) = -28800  (UTC-8)
// PDT (Pacific Daylight Time) = -25200  (UTC-7)
// ═══════════════════════════════════════════════════════════════════════

/* Timezone configuration for Central Time Zone */
long gmtOffsetSec = TIMEZONE_OFFSET_SEC;
int daylightOffsetSec = 0;      // Not using DST offset

/* Update timers */
unsigned long lastWatchFaceUpdate = 0;
const unsigned long WATCH_FACE_UPDATE_INTERVAL = 1000;  // Update every second

/* Battery monitoring configuration */
// BATTERY_ADC_PIN is defined in platformio.ini
const float BATTERY_MAX_VOLTAGE = 3.36;  // 100% battery voltage
const float BATTERY_MIN_VOLTAGE = 2.64;  // 0% battery voltage
const float ADC_VOLTAGE_REF = 3.3;       // ESP32-S3 ADC reference voltage
const int ADC_MAX_VALUE = 4095;          // 12-bit ADC

/**
 * @brief Read battery percentage from ADC pin
 * @return Battery percentage (0-100)
 */
int readBatteryPercentage() {
    // Read ADC value from GPIO1
    int adcValue = analogRead(BATTERY_ADC_PIN);
    
    // Convert ADC value to voltage
    // Using default attenuation (ADC_11db) which supports 0-3.9V range
    float voltage = (adcValue / (float)ADC_MAX_VALUE) * ADC_VOLTAGE_REF;
    
    // Map voltage to percentage (2.64V = 0%, 3.36V = 100%)
    float percentage = ((voltage - BATTERY_MIN_VOLTAGE) / (BATTERY_MAX_VOLTAGE - BATTERY_MIN_VOLTAGE)) * 100.0;
    
    // Clamp percentage to 0-100 range
    if (percentage < 0) percentage = 0;
    if (percentage > 100) percentage = 100;
    
    return (int)percentage;
}

void setup() {
    Serial.begin(115200);
    // No COM port wait - allows immediate streaming for FPGA/direct bus reading
    // Serial will work either way, data is available on the bus immediately
    
    Serial.println();
    Serial.println(F("  ___                  __        __    _       _     "));
    Serial.println(F(" / _ \\ _ __   ___ _ _\\ \\      / /_ _| |_ ___| |__  "));
    Serial.println(F("| | | | '_ \\ / _ \\ '_ \\ \\ /\\ / / _` | __/ __| '_ \\ "));
    Serial.println(F("| |_| | |_) |  __/ | | \\ V  V / (_| | || (__| | | |"));
    Serial.println(F(" \\___/| .__/ \\___|_| |_|\\_/\\_/ \\__,_|\\__\\___|_| |_|"));
    Serial.println(F("      |_|                                           "));
    Serial.println();
    Serial.println(F("=== OpenWatch - LVGL Edition ==="));
    Serial.println(F("Starting up..."));

    /* Set GPIO 17 to HIGH (power rail) */
    pinMode(17, OUTPUT);
    digitalWrite(17, HIGH);
    Serial.println(F("GPIO 17 set to HIGH (power rail for peripherals)"));
    Serial.println(F("Waiting for peripherals to power up..."));
    delay(200);  // CST816S needs time to boot after power-on
    Serial.println(F("Power rail stabilized"));
    
    /* Configure ADC for battery monitoring */
    analogReadResolution(12);  // 12-bit resolution (0-4095)
    analogSetAttenuation(ADC_11db);  // 0-3.9V range (default for ESP32-S3)
    pinMode(BATTERY_ADC_PIN, INPUT);
    Serial.printf("Battery ADC configured on GPIO%d (12-bit, 0-3.9V range)\n", BATTERY_ADC_PIN);

    /* CPU frequency check */
    Serial.printf("CPU Frequency: %d MHz\n", getCpuFrequencyMhz());

    /* Initialize SPI bus for display */
    Serial.println(F("Initializing SPI bus for display..."));
    displaySPI.begin(TFT_SCK_PIN, TFT_MISO_PIN, TFT_MOSI_PIN, TFT_CS_PIN);
    Serial.println(F("SPI bus initialized"));

    /* Initialize display with LVGL */
    Serial.println(F("Initializing LVGL display..."));
    lvgl_display_init(&tft);
    Serial.println(F("LVGL display initialized"));
    delay(50);  // Brief delay after display init before I2C operations
    
    /* Show splash screen (temporary) */
    Serial.println(F("Creating splash screen..."));
    lv_obj_t *splash_screen = lv_obj_create(NULL);
    lv_obj_set_style_bg_color(splash_screen, lv_color_hex(0x000000), 0);
    
    Serial.println(F("Creating splash label..."));
    lv_obj_t *splash_label = lv_label_create(splash_screen);
    lv_label_set_text(splash_label, "OpenWatch");
    lv_obj_set_style_text_font(splash_label, &lv_font_montserrat_14, 0);
    lv_obj_set_style_text_color(splash_label, lv_color_hex(0x00d9ff), 0);
    lv_obj_center(splash_label);
    
    Serial.println(F("Loading splash screen..."));
    lv_scr_load(splash_screen);
    
    Serial.println(F("Running LVGL timer handler..."));
    lv_timer_handler();
    delay(1000);
    
    Serial.println(F("Splash screen shown, will be replaced by watch face"));
    Serial.flush();

    /* Initialize I2C for sensors (touch controller, etc.) */
    Serial.println(F("Initializing I2C..."));
    Wire.begin(TOUCH_SDA_PIN, TOUCH_SCL_PIN);  // SDA=8, SCL=9 (shared with sensors)
    Wire.setClock(100000);  // 100kHz for better reliability with CST816S
    Wire.setTimeout(100);   // 100ms timeout
    Serial.printf("I2C initialized on SDA=%d, SCL=%d at 100kHz\n", TOUCH_SDA_PIN, TOUCH_SCL_PIN);
    delay(50);  // Let I2C bus stabilize
    
    /* Scan I2C bus to detect devices */
    Serial.println(F("Scanning I2C bus for devices..."));
    int devicesFound = 0;
    for (byte address = 1; address < 127; address++) {
        Wire.beginTransmission(address);
        byte error = Wire.endTransmission();
        if (error == 0) {
            Serial.printf("  ✓ I2C device found at 0x%02X\n", address);
            devicesFound++;
        } else if (error == 4) {
            Serial.printf("  ✗ Unknown error at 0x%02X\n", address);
        }
        delay(10);  // Small delay between scans
    }
    if (devicesFound == 0) {
        Serial.println(F("  ✗ NO I2C devices found!"));
        Serial.println(F("  Check connections: SDA=8, SCL=9, Power=GPIO17"));
    } else {
        Serial.printf("  Found %d I2C device(s)\n", devicesFound);
    }
    Serial.println(F("I2C scan complete"));
    
    /* Initialize sensors (BMP280, BNO055, MAX30102, GPS) */
    Serial.println(F("Initializing sensors..."));
    Serial.flush();
    sensor_handler_init();
    Serial.println(F("Sensor initialization complete"));
    Serial.flush();
    
    /* Initialize touch input */
    Serial.println(F("Initializing touch input..."));
    Serial.flush();
    lvgl_touch_init();
    touchInitialized = lvgl_touch_is_ready();
    if (touchInitialized) {
        Serial.println(F("Touch input initialized successfully"));
    } else {
        Serial.println(F("Touch input failed - will retry in background"));
    }
    Serial.flush();

    /* Ensure WiFi runs on Core 0, leaving Core 1 for LVGL/Touch */
    Serial.println(F("Configuring WiFi to run on Core 0..."));
    WiFi.useStaticBuffers(true);  // Use static buffers for better performance
    
    /* Start WiFi connection in background (non-blocking) */
    Serial.println(F("Starting WiFi connection in background..."));
    Serial.flush();
    WiFi.mode(WIFI_STA);
    WiFi.begin(WIFI_SSID, WIFI_PASS);
    lastWiFiAttempt = millis();
    Serial.println(F("WiFi init started - will connect in background"));
    Serial.flush();

    /* Initialize buttons */
    Serial.println(F("Initializing buttons..."));
    Serial.flush();
    button.begin();
    Serial.println(F("Primary button initialized"));
    Serial.flush();
    
    menuButton.begin();
    Serial.println(F("Menu button initialized"));
    Serial.flush();
    
    /* GPIO14 is MENU_BUTTON_PIN (already initialized above as menuButton) */
    /* GPIO18 is BUTTON_PRIMARY_PIN (already initialized above as button) */
    /* GPIO18 power button functionality added in loop */
    Serial.printf("GPIO14 (Menu/Home) and GPIO18 (Primary/Power) configured\n");
    
    Serial.printf("Initial button states - Primary (GPIO %d): %d, Menu (GPIO %d): %d\n", 
        BUTTON_PRIMARY_PIN, digitalRead(BUTTON_PRIMARY_PIN), 
        MENU_BUTTON_PIN, digitalRead(MENU_BUTTON_PIN));
    
    /* Wake-up configuration removed - sleep functionality not used */
    
    /* Initialize vibration motor */
    Serial.println(F("Initializing vibration motor..."));
    Serial.flush();
    vibration_init();
    Serial.println(F("Vibration motor initialized"));
    Serial.flush();

    /* Initialize watch face - this will replace splash screen */
    Serial.println(F("Creating watch face..."));
    Serial.flush();
    watch_face_init();  // This calls lv_scr_load() internally
    Serial.println(F("Watch face created and loaded"));
    Serial.flush();
    
    watch_face_set_connectivity_status(false, false);  // Start in WiFi mode, disconnected
    watch_face_set_time_synced(false);
    
    /* Read initial battery level from ADC */
    int initialBattery = readBatteryPercentage();
    watch_face_set_battery(initialBattery, false);
    Serial.printf("Initial battery level: %d%%\n", initialBattery);
    
    watch_face_set_steps(0);            // Initial step count (will be updated by sensor)
    watch_face_set_heart_rate(0);       // No heart rate data yet
    Serial.println(F("Watch face status set"));
    Serial.flush();
    
    /* Initialize BLE handler (not started unless mode is switched) */
    Serial.println(F("Initializing BLE handler..."));
    Serial.flush();
    ble_handler_init();
    Serial.println(F("BLE handler initialized (inactive)"));
    Serial.flush();
    
    /* Initialize app manager for multi-screen navigation */
    Serial.println(F("Initializing app manager..."));
    Serial.flush();
    app_manager_init();
    Serial.println(F("App manager initialized"));
    Serial.flush();
    
    /* Delete splash screen to free memory */
    Serial.println(F("Deleting splash screen..."));
    lv_obj_del(splash_screen);
    Serial.println(F("Splash screen deleted"));
    Serial.flush();
    
    /* Force immediate update */
    lastWatchFaceUpdate = 0;
    
    Serial.println(F("Forcing immediate display refresh..."));
    Serial.flush();
    
    /* Force LVGL to refresh NOW - this is critical for screen transitions */
    lv_refr_now(NULL);
    Serial.println(F("lv_refr_now() completed"));
    Serial.flush();
    
    Serial.println(F("Running LVGL timer handlers..."));
    Serial.flush();
    lv_timer_handler();
    lv_timer_handler();
    lv_timer_handler();
    Serial.println(F("LVGL timers completed"));
    Serial.flush();
    
    Serial.println(F("Boot complete - Watch face active"));
    Serial.println(F("Check display now - should see watch face"));
    Serial.printf("Free heap: %d bytes\n", ESP.getFreeHeap());
    Serial.flush();
}

void loop() {
    static bool firstLoop = true;
    if (firstLoop) {
        Serial.println(F("[LOOP] Entered main loop on Core "));
        Serial.println(xPortGetCoreID());
        Serial.flush();
        firstLoop = false;
    }
    
    unsigned long now = millis();
    static unsigned long lastBackgroundTasks = 0;
    static unsigned long lastLvglCall = 0;
    
    /* Handle LVGL tasks FIRST and FREQUENTLY (critical for touch responsiveness) */
    /* Call every ~5ms for smooth 200Hz polling rate */
    if (now - lastLvglCall >= 5 || lastLvglCall == 0) {
        lv_timer_handler();
        lastLvglCall = now;
    }
    
    /* ============================================
     * Touch retry (if not initialized)
     * ============================================ */
    if (!touchInitialized && (now - lastTouchRetry > TOUCH_RETRY_INTERVAL)) {
        lastTouchRetry = now;
        // Silently retry - only report success
        lvgl_touch_init();
        touchInitialized = lvgl_touch_is_ready();
        if (touchInitialized) {
            Serial.println(F("[Touch] ✓ Touch controller initialized successfully!"));
        }
    }
    
    /* ============================================
     * Button handling
     * ============================================ */
    ButtonEvent primaryEvent = button.update();
    ButtonEvent menuEvent = menuButton.update();

    /* Debug button events */
    if (primaryEvent != ButtonEvent::NONE) {
        Serial.printf("[BTN] Primary: %s\n", 
                      primaryEvent == ButtonEvent::SHORT_PRESS ? "SHORT" : "LONG");
    }
    if (menuEvent != ButtonEvent::NONE) {
        Serial.printf("[BTN] Menu: %s\n", 
                      menuEvent == ButtonEvent::SHORT_PRESS ? "SHORT" : "LONG");
    }

    /* Long press primary button -> removed (GPIO18 now used for power menu) */
    // Sleep function removed from GPIO18
    
    /* Menu button (GPIO14) functionality moved above to return to watch face */
    /* WiFi toggle functionality removed to use GPIO14 as home button */
    
    /* ============================================
     * GPIO14 - Home button (return to watch face)
     * Note: GPIO14 is MENU_BUTTON_PIN, so we use the menuButton short press
     * ============================================ */
    if (menuEvent == ButtonEvent::SHORT_PRESS) {
        // GPIO14 short press returns to watch face from any menu
        if (app_manager_get_current() != AppType::WATCH_FACE && app_manager_get_current() != AppType::POWER_MENU) {
            Serial.println(F("[GPIO14] Menu button - returning to watch face"));
            app_manager_return_home();
        }
    }
    
    /* ============================================
     * GPIO18 - Power menu button (3-second hold)
     * Using ButtonHandler for better debouncing
     * ============================================ */
    bool gpio18_current = button.isButtonPressed();
    
    if (gpio18_current && !gpio18_pressed) {
        // Button just pressed
        gpio18_pressed = true;
        gpio18_press_start = now;
        power_menu_shown = false;
        Serial.println(F("[GPIO18] Power button pressed - waiting for 3 seconds..."));
    } else if (!gpio18_current && gpio18_pressed) {
        // Button released
        gpio18_pressed = false;
        power_menu_shown = false;
        Serial.println(F("[GPIO18] Power button released"));
    } else if (gpio18_current && gpio18_pressed && !power_menu_shown && (now - gpio18_press_start >= 3000)) {
        // Held for 3 seconds
        power_menu_shown = true;
        Serial.println(F("[GPIO18] Power button held for 3 seconds - showing power menu"));
        app_manager_navigate_to(AppType::POWER_MENU);
    }
    
    /* ============================================
     * Sensor updates (rate limited internally to 200ms)
     * ============================================ */
    sensor_handler_update();
    
    /* ============================================
     * BLE updates
     * ============================================ */
    ble_handler_update();
    
    /* ============================================
     * Background tasks (WiFi, NTP, BLE time sync, etc.)
     * ============================================ */
    if (now - lastBackgroundTasks > 1000) {  // Every second
        lastBackgroundTasks = now;
        
        /* Check connection mode */
        ConnectionMode mode = ble_handler_get_mode();
        
        /* WiFi connection handling - non-blocking */
        wl_status_t wifiStatus = WiFi.status();
        bool wifiConnected = (wifiStatus == WL_CONNECTED);
        
        if (mode == ConnectionMode::WIFI) {
            /* If WiFi just connected, configure NTP (sets RTC - persists without WiFi!) */
            static bool ntpConfigured = false;
            if (wifiConnected && !ntpConfigured) {
                Serial.println(F("[WiFi] Connected! Configuring NTP..."));
                Serial.printf("IP: %s\n", WiFi.localIP().toString().c_str());
                Serial.println(F("[NTP] Configuring time servers (sets ESP32 RTC)..."));
                configTime(gmtOffsetSec, daylightOffsetSec, "pool.ntp.org", "time.nist.gov");
                ntpConfigured = true;
                lastNtpAttempt = now;
            }
            
            /* Check if time is synced (RTC persists even without WiFi) */
            if (!timeSynced) {
                time_t nowTime = time(nullptr);
                if (nowTime > 100000) {
                    // Time is valid - either just synced or RTC is maintaining it
                    timeSynced = true;
                    struct tm timeinfo;
                    getLocalTime(&timeinfo);
                    
                    if (wifiConnected) {
                        Serial.println(F("[NTP] Time synced successfully from NTP!"));
                    } else {
                        Serial.println(F("[RTC] Time already set in RTC (persists without WiFi)"));
                    }
                    
                    Serial.printf("Current time: %04d-%02d-%02d %02d:%02d:%02d\n", 
                        timeinfo.tm_year + 1900, timeinfo.tm_mon + 1, timeinfo.tm_mday,
                        timeinfo.tm_hour, timeinfo.tm_min, timeinfo.tm_sec);
                }
            }
            
            /* Handle WiFi reconnection */
            handleWiFiReconnection(now, lastWiFiAttempt);
            
            /* Handle NTP time sync */
            handleNTPRetry(now, timeSynced, gmtOffsetSec, daylightOffsetSec, lastNtpAttempt);
            
        } else {
            /* BLE mode - check for time sync */
            if (ble_handler_time_synced() && !timeSynced) {
                Serial.println(F("[BLE] Time synced via BLE!"));
                timeSynced = true;
            }
        }
        
        /* Update connectivity indicator on watch face */
        if (mode == ConnectionMode::BLE) {
            watch_face_set_connectivity_status(ble_handler_is_connected(), true);
        } else {
            watch_face_set_connectivity_status(wifiConnected, false);
        }
        
        watch_face_set_time_synced(timeSynced);
        
        // Read actual battery level from ADC
        int batteryLevel = readBatteryPercentage();
        watch_face_set_battery(batteryLevel, false);
        
        // Note: Steps and heart rate are updated in watch_face_update() from real sensors
    }

    /* ============================================
     * Watch face and app updates
     * ============================================ */
    if (now - lastWatchFaceUpdate >= WATCH_FACE_UPDATE_INTERVAL) {
        lastWatchFaceUpdate = now;
        
        /* Update current app/screen */
        app_manager_update();
        
        /* Force display refresh after update */
        lv_refr_now(NULL);
    }
    
    /* No delay needed - LVGL handler provides timing control */
    /* This allows maximum touch responsiveness */
}

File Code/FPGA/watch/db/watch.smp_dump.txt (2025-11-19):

State Machine - |de2i_150_top|lcd_driver:lcd_inst|next_state_after_delay
Name next_state_after_delay.S_IDLE next_state_after_delay.S_DISP_ON next_state_after_delay.S_ENTRY_MODE next_state_after_delay.S_DISP_CLEAR next_state_after_delay.S_DISP_OFF next_state_after_delay.S_FUNC_SET next_state_after_delay.S_INIT_3 next_state_after_delay.S_INIT_2 
next_state_after_delay.S_INIT_2 0 0 0 0 0 0 0 0 
next_state_after_delay.S_INIT_3 0 0 0 0 0 0 1 1 
next_state_after_delay.S_FUNC_SET 0 0 0 0 0 1 0 1 
next_state_after_delay.S_DISP_OFF 0 0 0 0 1 0 0 1 
next_state_after_delay.S_DISP_CLEAR 0 0 0 1 0 0 0 1 
next_state_after_delay.S_ENTRY_MODE 0 0 1 0 0 0 0 1 
next_state_after_delay.S_DISP_ON 0 1 0 0 0 0 0 1 
next_state_after_delay.S_IDLE 1 0 0 0 0 0 0 1 

State Machine - |de2i_150_top|lcd_driver:lcd_inst|state
Name state.S_DELAY state.S_HOLD state.S_WAIT_EN state.S_IDLE state.S_DISP_ON state.S_ENTRY_MODE state.S_DISP_CLEAR state.S_DISP_OFF state.S_FUNC_SET state.S_INIT_3 state.S_INIT_2 state.S_INIT_1 state.S_PWR_UP 
state.S_PWR_UP 0 0 0 0 0 0 0 0 0 0 0 0 0 
state.S_INIT_1 0 0 0 0 0 0 0 0 0 0 0 1 1 
state.S_INIT_2 0 0 0 0 0 0 0 0 0 0 1 0 1 
state.S_INIT_3 0 0 0 0 0 0 0 0 0 1 0 0 1 
state.S_FUNC_SET 0 0 0 0 0 0 0 0 1 0 0 0 1 
state.S_DISP_OFF 0 0 0 0 0 0 0 1 0 0 0 0 1 
state.S_DISP_CLEAR 0 0 0 0 0 0 1 0 0 0 0 0 1 
state.S_ENTRY_MODE 0 0 0 0 0 1 0 0 0 0 0 0 1 
state.S_DISP_ON 0 0 0 0 1 0 0 0 0 0 0 0 1 
state.S_IDLE 0 0 0 1 0 0 0 0 0 0 0 0 1 
state.S_WAIT_EN 0 0 1 0 0 0 0 0 0 0 0 0 1 
state.S_HOLD 0 1 0 0 0 0 0 0 0 0 0 0 1 
state.S_DELAY 1 0 0 0 0 0 0 0 0 0 0 0 1 

State Machine - |de2i_150_top|uart_rx:uart_inst|state
Name state.S_STOP_BIT state.S_DATA_BITS state.S_START_BIT state.S_IDLE state.S_CLEANUP 
state.S_IDLE 0 0 0 0 0 
state.S_START_BIT 0 0 1 1 0 
state.S_DATA_BITS 0 1 0 1 0 
state.S_STOP_BIT 1 0 0 1 0 
state.S_CLEANUP 0 0 0 1 1 

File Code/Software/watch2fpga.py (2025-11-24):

#!/usr/bin/env python3
"""
Serial Port Forwarder with LCD Formatting
Reads sensor data from COM15, formats it for 16x2 LCD, and sends to COM5
"""

import serial
import sys
import time
import re


def clean_special_chars(text):
    """Remove special characters like degree symbols, mu, etc."""
    text = text.replace('°', '')
    text = text.replace('µ', 'u')
    text = text.replace('²', '2')
    return text


def parse_bmp280(line):
    """Parse BMP280 sensor line and format for LCD"""
    # BMP280: Temp: 35.48°C, Pressure: 1013.75 hPa
    temp_match = re.search(r'Temp:\s*([\d.]+)', line)
    pressure_match = re.search(r'Pressure:\s*([\d.]+)', line)
    
    if temp_match and pressure_match:
        temp = float(temp_match.group(1))
        pressure = float(pressure_match.group(1))
        return [
            f"Temp: {temp:.1f}C",
            f"Press: {pressure:.0f}hPa"
        ]
    return None


def parse_bno055_accel(line):
    """Parse BNO055 accelerometer line"""
    # Accel: X=-1.45 Y=-1.12 Z=-9.56 m/s²
    x_match = re.search(r'X=([-\d.]+)', line)
    y_match = re.search(r'Y=([-\d.]+)', line)
    z_match = re.search(r'Z=([-\d.]+)', line)
    
    if x_match and y_match and z_match:
        x = float(x_match.group(1))
        y = float(y_match.group(1))
        z = float(z_match.group(1))
        return [
            f"Accel X:{x:+.1f}",
            f"Y:{y:+.1f} Z:{z:+.1f}"
        ]
    return None


def parse_bno055_gyro(line):
    """Parse BNO055 gyroscope line"""
    # Gyro:  X=0.00 Y=-0.12 Z=0.19 rad/s
    x_match = re.search(r'X=([-\d.]+)', line)
    y_match = re.search(r'Y=([-\d.]+)', line)
    z_match = re.search(r'Z=([-\d.]+)', line)
    
    if x_match and y_match and z_match:
        x = float(x_match.group(1))
        y = float(y_match.group(1))
        z = float(z_match.group(1))
        return [
            f"Gyro X:{x:+.2f}",
            f"Y:{y:+.2f} Z:{z:+.2f}"
        ]
    return None


def parse_bno055_mag(line):
    """Parse BNO055 magnetometer line"""
    # Mag:   X=-247.25 Y=6.75 Z=13.00 µT
    x_match = re.search(r'X=([-\d.]+)', line)
    y_match = re.search(r'Y=([-\d.]+)', line)
    z_match = re.search(r'Z=([-\d.]+)', line)
    
    if x_match and y_match and z_match:
        x = float(x_match.group(1))
        y = float(y_match.group(1))
        z = float(z_match.group(1))
        return [
            f"Mag X:{x:+.0f}uT",
            f"Y:{y:+.0f} Z:{z:+.0f}"
        ]
    return None


def parse_bno055_orient(line):
    """Parse BNO055 orientation line"""
    # Orient: Pitch=-8.38° (inc), Yaw=162.75° (azm), Roll=175.19° (toolface)
    pitch_match = re.search(r'Pitch=([-\d.]+)', line)
    yaw_match = re.search(r'Yaw=([-\d.]+)', line)
    roll_match = re.search(r'Roll=([-\d.]+)', line)
    
    if pitch_match and yaw_match and roll_match:
        pitch = float(pitch_match.group(1))
        yaw = float(yaw_match.group(1))
        roll = float(roll_match.group(1))
        return [
            f"Pitch:{pitch:+.1f}",
            f"Yaw:{yaw:.0f} R:{roll:.0f}"
        ]
    return None


def parse_max30102(line):
    """Parse MAX30102 heart rate sensor line"""
    # MAX30102: HR: 72 BPM, SpO2: 98%
    hr_match = re.search(r'HR:\s*(\d+)\s*BPM', line)
    spo2_match = re.search(r'SpO2:\s*(\d+)', line)
    
    if hr_match and spo2_match:
        hr = int(hr_match.group(1))
        spo2 = int(spo2_match.group(1))
        return [
            f"Heart Rate:{hr}BPM",
            f"SpO2: {spo2}%"
        ]
    return None


def parse_sensor_data(buffer):
    """Parse sensor data from buffer and extract formatted LCD lines"""
    lcd_data = []
    lines = buffer.split('\n')
    
    for i, line in enumerate(lines):
        line = line.strip()
        
        # BMP280 sensor
        if 'BMP280:' in line:
            result = parse_bmp280(line)
            if result:
                lcd_data.append(('BMP280', result))
        
        # BNO055 Accelerometer
        elif 'Accel:' in line:
            result = parse_bno055_accel(line)
            if result:
                lcd_data.append(('BNO055_ACCEL', result))
        
        # BNO055 Gyroscope
        elif 'Gyro:' in line:
            result = parse_bno055_gyro(line)
            if result:
                lcd_data.append(('BNO055_GYRO', result))
        
        # BNO055 Magnetometer
        elif 'Mag:' in line:
            result = parse_bno055_mag(line)
            if result:
                lcd_data.append(('BNO055_MAG', result))
        
        # BNO055 Orientation
        elif 'Orient:' in line:
            result = parse_bno055_orient(line)
            if result:
                lcd_data.append(('BNO055_ORIENT', result))
        
        # MAX30102 Heart Rate Sensor
        elif 'MAX30102:' in line and 'HR:' in line:
            result = parse_max30102(line)
            if result:
                lcd_data.append(('MAX30102', result))
    
    return lcd_data


def send_to_lcd(output_serial, line1, line2):
    """Send two lines to LCD via serial port"""
    # FPGA treats display as 40x2, so pad each line to 40 chars
    # Physical display is 16x2, so only first 16 chars of each line are visible
    line1 = line1[:16].ljust(40)  # Pad to 40 chars (16 visible + 24 blank)
    line2 = line2[:16].ljust(40)  # Pad to 40 chars (16 visible + 24 blank)
    
    # Send both lines
    output_serial.write(line1.encode('ascii'))
    output_serial.write(line2.encode('ascii'))
    output_serial.flush()
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

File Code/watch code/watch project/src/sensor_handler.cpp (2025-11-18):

/**
 * @file sensor_handler.cpp
 * @brief Sensor management implementation for smartwatch
 */

#include "sensor_handler.h"
#include <Wire.h>
#include <WiFi.h>
#include <Adafruit_BMP280.h>
#include <Adafruit_BNO055.h>
#include <Adafruit_Sensor.h>
#include <MAX30105.h>
#include <TinyGPSPlus.h>
#include <HardwareSerial.h>

/* Sensor objects */
static Adafruit_BMP280 bmp280;
static Adafruit_BNO055 bno055 = Adafruit_BNO055(55);
static MAX30105 max30102;
static TinyGPSPlus gps;
static HardwareSerial gpsSerial(1);  // Use UART1

/* Sensor availability flags */
static bool bmp280_available = false;
static bool bno055_available = false;
static bool max30102_available = false;
static bool gps_available = false;

/* Sensor data storage */
static BMP280Data bmp280_data = {0, 0, false};
static BNO055Data bno055_data = {0, 0, 0, 0, 0, 0, 0, 0, 0, 0, 0, 0, false};
static MAX30102Data max30102_data = {0, 0, false};
static GPSData gps_data = {0, 0, 0, 0, 0, false};

/* Step counter variables */
static int step_count = 0;
static float last_accel_magnitude = 0;
static unsigned long last_step_time = 0;
static bool step_peak_detected = false;
#define STEP_THRESHOLD 1.2        // Acceleration change threshold (m/s²)
#define STEP_MIN_INTERVAL 250     // Minimum time between steps (ms)
#define STEP_DEBOUNCE 100         // Debounce time (ms)

/* Streaming state */
static bool streaming_enabled = false;

/* Update tracking */
static unsigned long last_sensor_update = 0;
static const unsigned long SENSOR_UPDATE_INTERVAL = 200;  // 200ms

/* Heart rate calculation variables */
static const int HR_SAMPLE_SIZE = 4;
static long hr_values[HR_SAMPLE_SIZE];
static int hr_value_count = 0;
static byte hr_sample_counter = 0;

/**
 * @brief Initialize BMP280 sensor
 */
static bool init_bmp280() {
    Serial.println(F("[Sensors] Initializing BMP280..."));
    
    if (bmp280.begin(ALTM_I2C_ADDR)) {
        /* Configure BMP280 */
        bmp280.setSampling(Adafruit_BMP280::MODE_NORMAL,     /* Operating Mode */
                          Adafruit_BMP280::SAMPLING_X2,      /* Temp. oversampling */
                          Adafruit_BMP280::SAMPLING_X16,     /* Pressure oversampling */
                          Adafruit_BMP280::FILTER_X16,       /* Filtering */
                          Adafruit_BMP280::STANDBY_MS_500);  /* Standby time */
        
        /* Give sensor time to stabilize and take first reading */
        delay(100);
        
        /* Perform a few dummy reads to flush out any bad initial values */
        for (int i = 0; i < 3; i++) {
            bmp280.readTemperature();
            bmp280.readPressure();
            delay(50);
        }
        
        Serial.println(F("[Sensors] ✓ BMP280 initialized"));
        return true;
    } else {
        Serial.println(F("[Sensors] ✗ BMP280 not found"));
        return false;
    }
}

/**
 * @brief Initialize BNO055 sensor
 */
static bool init_bno055() {
    Serial.println(F("[Sensors] Initializing BNO055..."));
    
    if (bno055.begin()) {
        delay(50);
        
        /* Set to NDOF mode (9-axis fusion) */
        bno055.setMode(OPERATION_MODE_NDOF);
        delay(20);
        
        /* Use external crystal for better accuracy */
        bno055.setExtCrystalUse(true);
        
        Serial.println(F("[Sensors] ✓ BNO055 initialized in NDOF mode"));
        return true;
    } else {
        Serial.println(F("[Sensors] ✗ BNO055 not found"));
        return false;
    }
}

/**
 * @brief Initialize MAX30102 sensor
 */
static bool init_max30102() {
    Serial.println(F("[Sensors] Initializing MAX30102..."));
    
    if (max30102.begin(Wire, I2C_SPEED_STANDARD, MAX30102_I2C_ADDR)) {
        /* Configure MAX30102 for heart rate and SpO2 */
        byte ledBrightness = 60;    // 0=Off to 255=50mA
        byte sampleAverage = 4;     // 1, 2, 4, 8, 16, 32
        byte ledMode = 2;           // 1 = Red only, 2 = Red + IR, 3 = Red + IR + Green
        byte sampleRate = 100;      // 50, 100, 200, 400, 800, 1000, 1600, 3200
        int pulseWidth = 411;       // 69, 118, 215, 411
        int adcRange = 4096;        // 2048, 4096, 8192, 16384
        
        max30102.setup(ledBrightness, sampleAverage, ledMode, sampleRate, pulseWidth, adcRange);
        
        Serial.println(F("[Sensors] ✓ MAX30102 initialized"));
        return true;
    } else {
        Serial.println(F("[Sensors] ✗ MAX30102 not found"));
        return false;
    }
}
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

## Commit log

2025-09-04 init commit
    [1_28inch-touch-lcd-sku24155.SLDASM, 1_28inch-touch-lcd-sku24155.stp, 91290A012_Alloy Steel Socket Head Screw.SLDPRT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]
2025-09-04 Added KiCad files
    [Smartwatch.kicad_pcb, Smartwatch.kicad_sch]
2025-09-05 PCB V1
    [Smartwatch.kicad_pcb, Smartwatch.kicad_sch]
2025-09-29 added teardrops, cleaned up a few traces
    [Smartwatch.kicad_pcb]
2025-10-01 gonna jump off a builing on facebook live
    [Smartwatch.kicad_pcb, Smartwatch.kicad_sch]
2025-10-01 cenetered charging pins?
    [Smartwatch.kicad_pcb]
2025-10-03 changed up PCB design, still WIP
    [Smartwatch.kicad_pcb, Smartwatch.kicad_sch]
2025-10-04 moved part around
    [Smartwatch.kicad_sch]
2025-10-06 final version of pcb
    [Smartwatch.kicad_pcb, Smartwatch.kicad_sch]
2025-10-06 uploaded final pcb
    [Smartwatch.kicad_sch]
2025-10-06 fixed kicad files
    [Smartwatch.kicad_pcb, Smartwatch.kicad_sch]
2025-10-07 Names Added
    [Smartwatch.kicad_pcb]
2025-10-07 prepared for production
    [Smartwatch.kicad_pcb, bom.csv, designators.csv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]
2025-10-10 Working display driver and graphical UI elements
2025-10-12 added pin diagram to code
2025-10-13 added touch functionality and minor bug fixes
    [app_manager.cpp, main.cpp, wifi_handler.cpp]
2025-10-22 Changed board to esp32 S3 and pin definitions
2025-10-28 Programming settings for esp32 s3
2025-10-30 updated wifi driver
2025-11-10 WIP: LVGL migration - mid-transition state
    [Smartwatch.step, Watch Assm.SLDASM, Watch Body.SLDPRT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]
2025-11-10 Complete LVGL migration - remove all old display code
    - Deleted old display system (app_manager, clock_display, display_adapter)
    - Removed old app implementations (calibration, fitness, timer, weather, wifi_app, altimeter)
    - Removed old touch system (touch_handler, touch_input)
    - Integrated CST816S touch driver directly into lvgl_touch
    - Cleaned up duplicate lv_conf.h files
    - Fixed merge conflict in main.cpp
    - Only date/time watch face remains functional
    [app_manager.cpp, lvgl_touch.cpp, main.cpp]
2025-11-10 Fix LVGL build - exclude ARM-specific assembly code
    - Added extra_script.py to filter out ARM Helium/NEON assembly files
    - Updated lv_conf.h to explicitly disable ARM hardware acceleration
    - Added build_unflags to remove ARM architecture defines
    - Added ESP32-specific build flags to prevent ARM code inclusion
    This fixes compilation errors where LVGL was trying to compile ARM assembly on ESP32-S3 (Xtensa)
2025-11-10 Downgrade LVGL to 8.3.11 and update API compatibility
    - Downgraded from LVGL 9.2 to 8.3.11 to avoid ARM assembly issues
    - Updated lvgl_display.cpp to use LVGL 8.3 API (lv_disp_drv_t)
    - Updated lvgl_touch.cpp to use LVGL 8.3 API (lv_indev_drv_t)
    - Fixed lv_refr_now() calls to use NULL parameter
    - LVGL 8.3 is more stable and doesn't include ARM Helium/NEON code
    [lvgl_display.cpp, lvgl_touch.cpp, main.cpp]
2025-11-10 Fix Adafruit BusIO BitOrder issue with library patching
    Root cause: ESP32 Arduino framework 3.x removed BitOrder enum, but
    Adafruit BusIO library still references it.
    Solution: Created extra_script.py that patches the BusIO library after
    download by injecting BitOrder typedef directly into Adafruit_SPIDevice.h
    This is more reliable than forced includes since it modifies the library
    source before compilation.
    Changes:
    - Rewrote extra_script.py to patch BusIO library
    - Removed forced include approach from platformio.ini
    - Deleted unused busio_compat.h header
2025-11-12 swapped all code to lvgl, still wip
    [app_manager.cpp, lvgl_display.cpp, lvgl_touch.cpp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]
2025-11-13 added sensor streaming and compass
2025-11-17 added battery monitoring
2025-11-18 added ble, weather, step counter, vibe, timer, gps, and more -- firmware 1.0.0 complete
2025-11-18 added new velco wrist band
    [Watch Body - Velcro.SLDPRT, Watch Body - Velcro.STEP]
